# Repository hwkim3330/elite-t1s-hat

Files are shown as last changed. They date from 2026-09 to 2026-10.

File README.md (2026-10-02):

# Elite T1S HAT

A **10BASE-T1S** board for the **LilyGO T-ETH-Elite** (ESP32-S3), built around
the Microchip **LAN8651** MAC-PHY. It stacks on the Elite's 2×20 header and
gives it a single-pair automotive Ethernet port next to the Elite's own
100BASE-TX (W5500). This board is its own design, not a Raspberry Pi HAT on an
adapter.

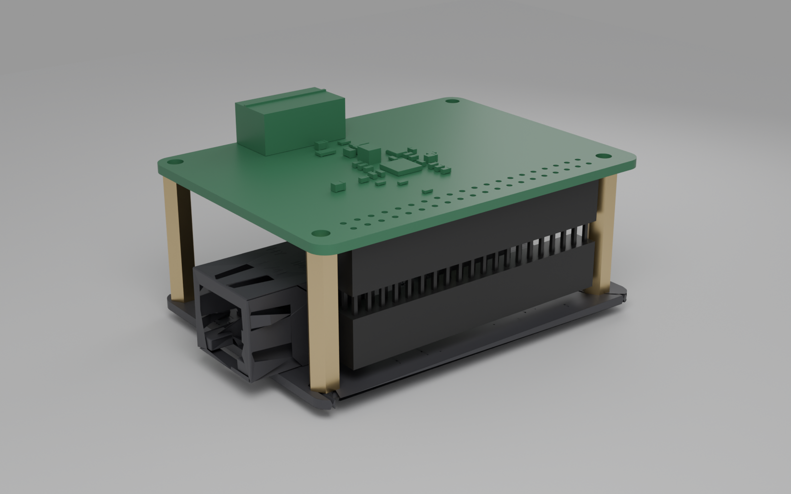
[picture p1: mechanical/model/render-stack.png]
The HAT on a T-ETH-Elite


**3D:** open [`mechanical/model/t1s_hat.stl`](mechanical/model/t1s_hat.stl) or
[`stack.stl`](mechanical/model/stack.stl) on GitHub to turn it in the browser.
There is also a STEP file for CAD work (`t1s_hat.step`).

| board, top | ground plane (In1) |
|---|---|
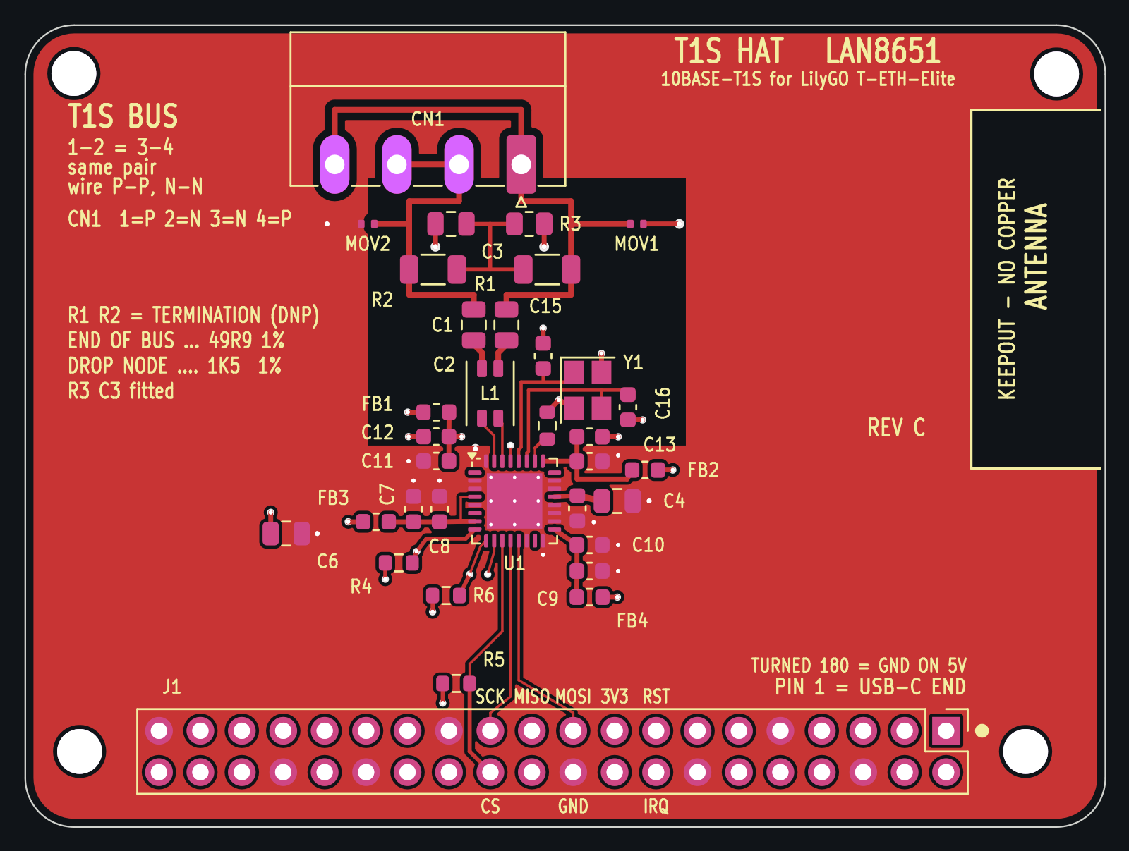
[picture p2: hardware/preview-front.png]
front
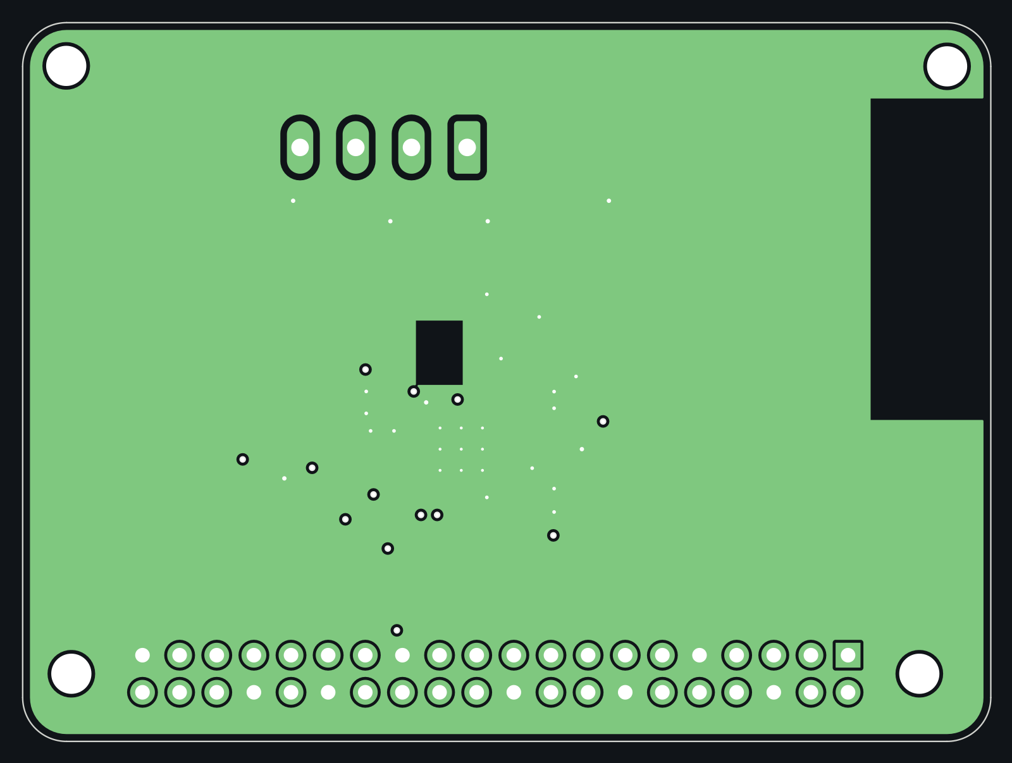
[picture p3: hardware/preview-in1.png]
In1.Cu
|  |  |

| folder | what |
|---|---|
| [`hardware/`](hardware/README.md) | KiCad schematic + **4-layer** PCB (Rev C; Rev B at tag `rev-b`), all generated by `make_t1s_hat.py`; gerbers; JLCPCB BOM/CPL. **[`ORDERING.md`](hardware/ORDERING.md) = how to order.** [`ELECTRICAL.md`](hardware/ELECTRICAL.md) = every value and why |
| [`firmware/`](firmware/README.md) | ESP32-S3 node firmware: LAN8651 over OPEN Alliance TC6 SPI, PLCA, ping/UDP, serial console |
| [`mechanical/`](mechanical/GEOMETRY.md) | outline, holes and header grid, measured from LilyGo's own DXF/3D (`reference/measure.py` re-derives them); `model/` has the 3D models (STL, STEP) and their build and render scripts |

## Status (2026-10-02)

| | |
|---|---|
| Design | **Rev C (4-layer) finished, ready to order**, with the pre-fabrication review fixes of 2026-10-02 (CCOMP, VDDAU, VDDA, RBIAS and crystal parts at their pins; exposed-pad paste clear of the thermal vias; see [`hardware/README.md`](hardware/README.md)). DRC 0 errors / 0 warnings, ERC 0 errors, mechanical error 0.00000 mm against `GEOMETRY.md`, 0 unrouted |
| Parts | every fitted part has an LCSC number, all in stock; **LAN8651 is the scarce one (199 at JLC, 2026-10-01)** |
| Firmware | compiles (Arduino esp32 3.3.0). It ran on a third-party LAN8651 HAT on the same pins (9.5 Mbit/s, PLCA, Zenoh); **not yet on this board, since none has been built** |
| Fabricated | **no.** Order 2–3 first, prove SPI + ping + PLCA between two nodes, then the rest |

What only a real board can settle is listed in
[`hardware/README.md`](hardware/README.md) under "What is NOT verified":
crystal oscillation margin, T1S signal quality and EMC, stack height.

## The short version of the design

- **LAN8651, single 3.3 V** from the Elite's header. The '51 regulates its own
  1.8 V core, so the board has no regulator.
- **Host SPI on the Elite's IO11/9/10, CS on IO0 (BOOT strap), IRQ IO39,
  RESET IO42.** These are the pins a Pi HAT would use, so the mainline
  `microchip,lan8651` driver also works on a Pi. Don't press BOOT on a
  running node.
- **Bus side per AN1718:** common-mode choke → 100 nF DC block → termination
  (fit per bus position: 49R9 end / 1K5 drop) → optional ESD → 4-pin 3.81 mm
  terminal block, wired P N N P so a node taps a daisy chain.
- **4 layers (since Rev B):** signals on top, In1 solid GND, In2 +3V3, bottom only three SPI escapes. The T1S pair is 50 Ω by construction (0.35 mm over 0.21 mm of prepreg). Rev A, the 2-layer version, is in git history.

## Where it is used

A networking test bench: ESP32-S3 nodes running Zenoh-pico behind two
TSN switches with FRER (IEEE 802.1CB). The nodes use the Elite's
own W5500 today; this HAT gives them a 10BASE-T1S edge link, and its firmware's
bridge mode joins a T1S segment to the switched 100BASE-TX backbone.

## History

Started as a sub-folder of an earlier adapter project (a Raspberry Pi HAT
carrier for the Elite) and split out on 2026-09-28 with its history, because the
board is its own product.

## License

MIT for everything written here; third-party parts keep their own licences
(listed in [`LICENSE`](LICENSE)).

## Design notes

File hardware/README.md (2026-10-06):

# T1S HAT — LAN8651 10BASE-T1S for the LilyGO T-ETH-Elite

Our own 10BASE-T1S board for the [LilyGO
T-ETH-Elite](https://github.com/Xinyuan-LilyGO/LilyGO-T-ETH-Series)
(ESP32-S3), built around a **Microchip LAN8651** MAC-PHY. It replaces buying
TSN Lab's ready-made HAT: same chip, same host header, our schematic.

Two source files govern this board and **nothing here re-derives a number in
either of them**:

| file | governs |
|---|---|
| [`ELECTRICAL.md`](ELECTRICAL.md) | every component, value and pin-handling rule, each quoted from Microchip DS60001734F or AN1718 (DS60001718D) |
| [`../mechanical/GEOMETRY.md`](../mechanical/GEOMETRY.md) | outline, mounting holes, 2×20 grid — measured from LilyGo's own DXF and 3D CAD |

Everything is generated by [`make_t1s_hat.py`](make_t1s_hat.py), which emits
the symbol library, the three project-local footprints, the schematic and the
PCB, then reads the board back and asserts every mechanical feature against
`GEOMETRY.md`.

**This is Rev C (2026-10-01, review fixes 2026-10-02), 4-layer: the design is
finished and ready to order.** Rev C is Rev B without the status LEDs and with
VDDA rerouted; an independent review before fabrication then moved the CCOMP,
VDDAU, VDDA and RBIAS parts and the crystal next to their pins and split U1's
exposed-pad paste (see "Rev C" below). It has not been ordered yet.
Rev B is at git tag `rev-b`. Rev A was 2-layer; its layout notes (the single-layer
crossings, JP1, the 3V3 rail) are in git history before commit "Rev B".

front

## What it is

- **LAN8651**, 32-VQFN 5×5, single 3.3 V rail (the '51 regulates its own 1.8 V
  core, so there is no second regulator and no sequencing diode).
- **OPEN Alliance TC6 SPI** to the host on the same header pins TSN Lab's
  device-tree overlay uses, so their SDK and the mainline `microchip,lan8651`
  driver both work unmodified if this board is ever put on a Pi.
- **Bus interface network** in AN1718's MINIMAL BIN order: common-mode choke →
  AC coupling caps → termination → ESD → 4-way 3.81 mm pluggable terminal
  block, wired so the node taps a daisy chain.
- **4 layers:** signals on top, In1.Cu solid GND, In2.Cu +3V3, bottom only the
  three SPI escapes. The T1S pair is 50 Ω by construction.
- 34 parts, 4 of them deliberately unstuffed (R1/R2 termination, MOV1/MOV2 ESD).

## The two parts that had to be chosen, not assumed

Both are drawn from their own data sheet into
[`fp/t1s_hat.pretty`](fp/t1s_hat.pretty), generated by `make_t1s_hat.py`
alongside the board, and the generator asserts the pad count and the overall
land size back out of the finished `.kicad_pcb`.

### L1 — TDK **ACT1210L-201-2P-TL00**, LCSC **C131444**

AN1718 names ACT1210D-131-2P-TL00, ACT1210E-241-2P-TL00 and Murata
DLW32MH241MX2, and says in the same breath that *"exact component part numbers
and parameters must be determined by the customer's unique application
requirements"* — they are examples. All three are **3.2 × 2.5 mm** (EIA 1210)
2-line chokes in the 130…240 µH @ 100 kHz band. The board previously sat on
KiCad's `Inductor_SMD:L_CommonMode_Wurth_WE-CNSW-1206`, a **3.2 × 1.6 mm**
land: same length, 0.9 mm too narrow, so the real part's terminals miss the
pads. KiCad ships no 4-terminal common-mode choke land in 3225.

The part fitted instead is the **ACT1210L-201-2P-TL00**: same ACT1210 package,
200 µH @ 100 kHz — inside the span AN1718's own examples cover — 70 mA,
5.5 Ω, AEC-Q200, and, unlike all three examples, **stocked at LCSC**
(C131444, ~$0.39/1k), which is where this board gets built.

Its land is `t1s_hat:L_CommonMode_TDK_ACT1210_3225`, drawn from TDK's ACT1210
data sheet "Layout recommendation" (drawing IND1512-9): **4.1 mm overall
across the pads with a 2.0 mm gap between the columns**, so each pad is
1.05 mm long on a 3.05 mm pitch, and **1.6 mm overall across the rows with a
0.4 mm gap**, so each pad is 0.60 mm wide on a 1.0 mm pitch. Body from the
same sheet: 3.2 ±0.2 long, 2.5 ±0.2 wide, 3.9 max over the terminals.

The symbol changed with it: the ACT1210's windings are **1-4 and 2-3**
(pin configuration and circuit diagram, same sheet), which is
`Device:L_Coupled_1423`, not the `…_1243` the 1206 Würth part needed.

### MOV1 / MOV2 — TDK **AVRH10C221KT1R5YA8**, LCSC **C2157827**

This is the part `ELECTRICAL.md` already names, and it is a **1005 [0402]**
chip varistor — 1.0 × 0.5 × 0.5 mm, 220 V V1mA, 70 V DC, **1.5 pF**, 25 kV per
IEC 61000-4-2. The board had it on `Resistor_SMD:R_1206_3216Metric`: three
size codes too big. It is now on `t1s_hat:Varistor_TDK_AVRH10_1005`, from the
recommended land pattern in TDK's automotive AVR chip-varistor catalogue
(pad 0.35…0.45 long, gap 0.3…0.5, pad 0.4…0.6 wide — the middle of each:
**0.40 long, 0.40 gap, 0.50 wide**). KiCad's `R_0402_1005Metric` is 0.54 ×
0.64 on a 1.02 mm pitch, outside all three ranges, which is why this one is
drawn here too. Both parts stay **DNP**; the land is now a real one.

## Rev B layout — what four layers bought

| | Rev A (2-layer) | Rev B (4-layer) |
|---|---|---|
| 3V3 | a rail round three sides of the board | **In2.Cu plane**, one via beside every 3V3 pad; no 3V3 trace exists |
| GND | B.Cu pour, one via per decoupling cap | **In1.Cu plane with no tracks at all**, plus F.Cu and B.Cu pours |
| VDDP pin 17 | 84 mm lap of the board through a 0 Ω jumper (JP1) | own ferrite-option island **FB4**, 0.01 + 0.1 µF at the pin |
| VDDP pin 7 | caps 7 mm away at the end of a column | C8 then C7 straight off the pin, FB3 behind them |
| SPI | MOSI looped out to the board edge and back; MISO ran between R5's pads | 2.5 mm fan-out: MISO/CS/SCLK drop through one via each to B.Cu, MOSI/IRQ/RESET stay on F.Cu, none crosses |
| T1S pair | 0.35 mm over 1.51 mm of FR4 — nowhere near 50 Ω | 0.35 mm over 0.21 mm of prepreg — **50.1 Ω** |

The rules the layout was held to, each checked by the generator or DRC:

- **In1.Cu and In2.Cu carry no tracks** (`plane tracks: 0`). Nothing slots the
  reference plane under the pair; the only cuts are the choke void AN1718
  asks for and the antenna window.
- **Every bus trace from the choke to CN1 is 0.35 mm** (`pair width` row).
- **Nothing passes between two vias.** The QFN's 0.5 mm pitch cannot fit a
  0.45 mm via plus 0.2 mm clearance each side with a track between, so the
  three B.Cu escapes are fanned out to a 1.1 mm pitch row first.
- **The B.Cu escapes turn right at staggered heights** (9 / 10 / 11 mm) and
  enter the header between pad columns, never across one of the Elite's
  pins that this board does not use.
- **The pull-ups cost no vias of their own:** R4 and R6 sit in-line on their
  F.Cu signal, and R5 lands on header pin 24's through-hole pad.

## Two decisions that are not in ELECTRICAL.md / GEOMETRY.md

### 1. No RJ45 notch — the outline is a plain rectangle

`GEOMETRY.md`'s notch exists because a board ~13 mm above the Elite would foul
the RJ45, which stands 15.97 mm. This board is lifted clear of the jack by a
taller riser instead, so nothing has to be cut away. Outline is the full
**66.22 × 49.19 mm rectangle, 3 mm corners**. Everything else mechanical in
`GEOMETRY.md` is unchanged and still authoritative: the four asymmetric
mounting holes and the 2×20 grid.

### 2. The connection is two-stage — read this before ordering parts

```
   T1S HAT  (this board)
        ↑ its 2x20 socket goes on the riser's long pins
   ── 2x20 stacking riser ──          ≈23 mm total (calculated), set by the riser
        ↑ riser socket swallows the Elite's own 9.30 mm pins
        ↑ RJ45 (15.97 mm) passes beside the stack, not through a notch
   LilyGO T-ETH-Elite (ESP32-S3)
```

**A single tall stacking header does not work here.** The Elite's pins are
only 9.30 mm long; they would reach barely halfway up a ~17 mm barrel whose
contacts sit near the top. You need a **riser** (a 2×20 stacking header that
plugs onto the Elite and presents longer pins) plus this board's **socket**.
That is a real failure mode someone will otherwise hit at the checkout page.

Board height above the Elite PCB is **≈23 mm, calculated** from the parts in
`ORDERING.md` (riser body 8.3 + ~6 mm of pin inside J1 + J1's 8.5 body), and set by the riser.
Nothing on this board depends on the exact number.

## Stack-up

JLCPCB **JLC04161H-7628**, 1.6 mm, written into the board file:

| layer | | thickness |
|---|---|---|
| F.Cu | signals, parts, GND flood | 0.035 mm (1 oz) |
| prepreg | 7628, εr 4.4 | 0.2104 mm |
| In1.Cu | **GND plane, no tracks** | 0.0152 mm (0.5 oz) |
| core | FR4 | 1.065 mm |
| In2.Cu | **+3V3 plane, no tracks** | 0.0152 mm (0.5 oz) |
| prepreg | 7628, εr 4.4 | 0.2104 mm |
| B.Cu | three SPI escapes + GND pour | 0.035 mm (1 oz) |

50 Ω single-ended on F.Cu over In1.Cu, IPC-2141:
Z0 = 87 / √(4.4 + 1.41) · ln(5.98 · 0.2104 / (0.8 · 0.35 + 0.035)) = **50.1 Ω**.
JLC's own calculator for this stack-up is the one to trust if it disagrees; ask
for impedance control when ordering and they will test it.

Design rules: 0.2 mm clearance (netclass), 0.15 mm minimum track, 0.45 mm vias
with 0.25 mm drill, 0.20 mm minimum drill (the QFN's thermal vias), and one
custom rule in `t1s_hat.kicad_dru`: **BUS_P/BUS_N keep 0.45 mm from every other
net** (pads, tracks, vias and the F.Cu flood). The one exception is inside each
MOV, whose own data-sheet land puts its BUS and GND pads 0.40 mm apart (the rule file relaxes clearance to 0.15 mm between pads inside each MOV courtyard, which covers that 0.40 mm gap).

## Termination stuffing — the one thing an assembler must decide

The board **ships with R1/R2 unstuffed**, per `ELECTRICAL.md` ("footprints
fitted, DNP by default — stuff per where this node sits on the bus"). The
silkscreen carries the table:

| where this node sits | R1, R2 |
|---|---|
| **end of the bus** | 49R9 1 % 1206 (AN1718: 1 W; the JLC variant fits 0.75 W — ORDERING.md) |
| **interior drop node** | 1K5 1 % 1206 |

`R3` (100 k) and `C3` (100 nF) — AN1718's common-mode termination — **are
fitted**. ESD elements MOV1/MOV2 have footprints and are DNP; `ELECTRICAL.md`
calls them optional.

`CN1` is wired **P N N P**, and the silkscreen carries that as a legend
(`CN1 1=P 2=N 3=N 4=P`) in the clear area to its left. Per-pad letters were
dropped: the four pads are 1.8 × 3.6 mm ovals with the connector's own body
outline 0.9 mm below them and R3/C3 0.6 mm below that, leaving a 0.6 mm slot —
nowhere to letter a pad without printing on copper. Pins 1–2 and 3–4 are the
same pair with opposite orientation, so wire P to P and N to N rather than
pin-for-pin. That order is what lets both on-board links be drawn without a
crossing.

## Verified

- **Mechanical: worst error 0.00000 mm** against `GEOMETRY.md`, tolerance
  0.01 mm, over the outline, all four mounting holes and all 40 header pads.
  `make_t1s_hat.py` prints the full table and exits non-zero on any failure.
- **Antenna keepout clean.** The generator walks every track, via, footprint
  and *filled zone polygon* on all four layers and counts anything inside
  x 58…66.22, y 22…44: **0 intruders.** The keepout is a rule area that forbids
  copper, tracks, vias, pads and footprints on all four layers, so both planes
  and both pours are cut out there. Silkscreen (ink, not copper) does mark the window.
- **In1.Cu and In2.Cu carry 0 tracks.** The T1S pair is 0.35 mm everywhere.
- **Unrouted connections: 0.**
- **L1 and MOV1/MOV2 lands read back as 4.10 × 1.60 mm on 4 pads and
  1.20 × 0.50 mm on 2 pads** — the data sheet numbers above, asserted out of
  the board file, not just written into it.
- **U1's exposed-pad paste covers no thermal via:** 12 windows, every one
  ≥ 0.15 mm off each of the nine 0.5 mm via lands, 51 % of the 3.4 mm land
  (`U1 EP paste` row).
- **ERC: 0 errors, 7 warnings** — see below.
- **DRC: 0 errors, 0 warnings, 0 unconnected** — see below.

### ERC — 0 errors

`kicad-cli` 7.0.11 has no `sch erc` subcommand, only `export`, so ERC is run
through the real eeschema on an Xvfb display by
[`run_erc.sh`](run_erc.sh), with **Show: All and Exclusions both ticked**
before the run. Report as produced: [`erc.rpt`](erc.rpt).

```
** ERC messages: 7  Errors 0  Warnings 7
```

All 7 warnings are the same thing: *"Pins of type Bidirectional and Power
output are connected"* on U1 pins 18, 19, 20, 22, 23 (DIOA0…4) and 16, 14
(DIOB0/DIOB1). Those are the unused configurable IO tied to ground, which is
exactly what the data sheet says to do — *"When not used, these pins may be
connected directly to ground."* Nothing is excluded or suppressed.

### DRC — 0 errors, 0 warnings

Run through `pcbnew.WriteDRCReport()` (same engine; `kicad-cli` has no
`pcb drc` either). Report as produced: [`drc.rpt`](drc.rpt).

```
** Found 0 DRC violations **
** Found 0 unconnected pads **
** Found 0 Footprint errors **
```

No clearance, hole, courtyard, keepout, solder-mask, silkscreen, unconnected-pad
or library-consistency finding. (The four mounting holes used to raise
`lib_footprint_issues`; their footprint is now written into the project library by
the generator itself, so the board copy and the library copy cannot differ.)
Nothing is excluded. Running it yourself reproduces exactly this.

## Inferences — things not taken from the spec files

Flagged because they are judgement, not quotation:

1. **U1 pin 1 (INH) is left unconnected.** `ELECTRICAL.md`'s pin-handling
   table does not cover INH. DS60001734F Table 3-5 says *"When not used, this
   pin should be left unconnected"*, so it is, with no copper stub.
2. **L1 is a 200 µH part where AN1718's examples are 130 and 240 µH.**
   AN1718 gives no minimum or maximum, only three example part numbers and an
   instruction to pick for the application; 200 µH is inside the span they
   cover and is the value TDK itself lists for one-pair automotive Ethernet.
   The land pattern is quoted, not inferred — but the *choice of value inside
   that span* is judgement.
3. **VDDP is split into two ferrite-option islands**, `VDDP` (pin 7, with
   TEST) on FB3 and `VDDP_17` (pin 17) on FB4. Both are fed from the same
   +3V3 plane, and with the default 0 Ω beads they are the same supply.
   `ELECTRICAL.md` asks for the bead option per supply; one per pin is the
   layout choice that keeps each pin's decoupling at the pin.
4. **The crystal is a 4-pad 3225, YXC X322525MOB4SI (C9006), CL 12 pF.**
   Until 2026-09-28 the board used a 2-pad 3.2 × 1.5 mm land. That was wrong:
   no 25 MHz crystal is made in that package, so the land matched no part.
   CL 12 pF rather than 18 pF is deliberate: 18 pF caps in series plus ~3 pF
   stray present 12 pF. Each lid pad (2, 4) has its own ground via; pad 2's is
   shared with R7's ground end beside it. Reasoning and margin numbers are in `ELECTRICAL.md`,
   "Clock".
5. **XTI is declared `passive` in the LAN8651 symbol**, not `input`. It is an
   oscillator pin driven by a passive crystal; declaring it an input makes
   KiCad's `pin_not_driven` test fire on a net that has no driver by design.
   Common practice, but it is a choice.
6. **The 40-pin header is a project-local symbol**, `t1s_hat:HAT_HEADER_2x20`,
   not `Connector_Generic:Conn_02x20_Odd_Even`. Its pins carry real electrical
   types (the six host signals are `output`/`input`, everything else
   `passive`), because the ESP32 side really is the driver and the generic
   connector's all-passive pins make ERC report every SPI input as undriven.
   The **footprint** is the stock `PinHeader_2x20_P2.54mm_Vertical`.
7. **Header pin 1 is at the USB-C (high-x) end, odd pins on the inner row
   (y = 5.900).** Rev A and early Rev B had this backwards (pin 1 at the low-x
   end on the edge row), inferred rather than measured. That was the exact
   180° opposite, and it would have put HAT GND on the Elite's 5 V. It is now
   taken from LilyGo's own pin-map image, cross-checked against the hole
   asymmetry and the antenna position (`../mechanical/GEOMETRY.md`), and
   asserted by the generator independently of `pin_xy()`: pin 1 must be the
   highest-x pad and on the inner row.
8. **`BIN_VOID` = x 21…40.5, y 23.4…39.8** and **`CMC_VOID` = x 26.90…30.10,
   y 24.40…28.80.** AN1718 asks for "a void in the ground flooding on the
   outside layer surrounding the BIN" and "an all-layer void underneath the
   CMC" **without giving dimensions**, so both sizes are judgement. The first
   follows the BIN components. The second is the only place other than the
   antenna window where the ground plane is cut, so it is sized to the
   part and no further: **the ACT1210's maximum body — 3.9 mm over the
   terminals × 2.7 mm wide (2.5 + tolerance) — plus 0.25 mm a side**, giving
   3.2 × 4.4 mm (L1 is rotated 90°, so the 3.9 runs along y). The margin
   covers placement tolerance and nothing else; the body is what couples to
   the plane, because the body is the core. That also covers the 4.1 × 1.6 mm
   land with room to spare. The void grew in x against the old number above,
   not because the margin grew but because the part did: the 1206 land it used
   to be sized around was the wrong part. Nothing but L1's own nets crosses it
   on any layer; VDDA passes on B.Cu 0.45 mm below it.
9. **The T1S pair necks to 0.15 mm at the QFN.** The package puts TRXP and
   TRXN 0.5 mm apart; AN1718's "3× trace width centre-to-centre to other
   signals" cannot be met between the pair's own two legs at a 0.5 mm-pitch
   QFN, and Microchip's own EVB does not either. It **is** met against every
   other net, by the F.Cu void around the BIN.
10. **Pair length match ≈0.2 mm.** TRXN opens out to the choke before TRXP
    does (so the gap only ever grows), which costs about 0.2 mm of mismatch —
    roughly 1.2 ps. Not measured on hardware.
11. **The stackup numbers** are JLCPCB's published JLC04161H-7628 build,
    taken as given, not measured. The 50 Ω figure follows from them.

## Files

| file | what |
|---|---|
| `ELECTRICAL.md` | **electrical source of truth** |
| [`ORDERING.md`](ORDERING.md) | **JLCPCB order: options, parts, what to hand-solder, what to check in the preview** |
| `jlcpcb/bom_jlc.csv` / `cpl_jlc.csv` | assembly files in JLC's column format, fitted SMT/THT parts only |
| [`../firmware/`](../firmware/README.md) | ESP32-S3 bring-up / node firmware (LAN8651 over TC6 SPI, PLCA, console) |
| `make_t1s_hat.py` | generator: symbol lib → schematic → PCB → verify → DRC → exports |
| `run_erc.sh` | runs eeschema's ERC headlessly (Xvfb + xdotool) and saves the report |
| `fill_zones.sh` | fills the zones through pcbnew's GUI — `ZONE_FILLER` segfaults in KiCad 7.0.11's Python bindings |
| `t1s_hat.kicad_sch` / `.kicad_pro` / `sym-lib-table` / `fp-lib-table` | schematic + project |
| `sym/t1s_hat.kicad_sym` | **LAN8651** (33 pins incl. the exposed pad) and the host header — neither exists in KiCad's libraries |
| `fp/t1s_hat.pretty/` | the TDK ACT1210 choke land and the TDK AVRH10 varistor land, each from that part's own data sheet — KiCad ships neither — and U1's QFN: KiCad's TQFN-32 5×5 with its exposed-pad paste split clear of the thermal vias |
| `t1s_hat.kicad_dru` | the custom DRC rule for the bus pair (written by the generator) |
| `t1s_hat.kicad_pcb` | the board |
| `gerbers/t1s_hat_gerbers.zip` | fab-ready: 10 gerber layers (4 copper), separate PTH/NPTH Excellon, drill maps, job file |
| `bom.csv` / `cpl.csv` | BOM (with a `Populate` column) and position file |
| `preview-front/back/in1/in2.png` (+ `.svg`) | all four copper layers |
| `erc.rpt` / `drc.rpt` | reports as produced, nothing excluded |

Regenerate with `python3 make_t1s_hat.py`. Geometry is reproducible to the
internal unit, but the output is not byte-reproducible — KiCad stamps fresh
UUIDs and timestamps on every run. Compare the printed coordinate table, not
the files.

Drill files and `cpl.csv` are plotted against the drill/place origin, which the
generator puts on `GEOMETRY.md`'s own origin, so `NPTH.drl` literally reads
`X3.33Y4.63` and `cpl.csv` reads `8.196, 3.360`.

## Bottom side

The board sits ~23 mm above the Elite. The J1 socket body occupies y 0…9 on
the bottom, and B.Cu carries only the three SPI escapes between the QFN and the
header. Everything else on the bottom is GND pour. Over the Elite's RJ45
(x −5.18…16.42, y 10.50…28.90) the clearance below is much less than
elsewhere, since the jack tops out at 15.17 mm above the Elite's PCB.

## Review notes (2026-09-29)

An external review of Rev B raised these; each was checked against the board
file and Microchip's documents before anything changed.

| point | finding | action |
|---|---|---|
| BUS_P 37.7 mm vs BUS_N 21.9 mm | True totals, but the **node's own stub is 15.92 mm on both**. The difference is the through-bus between CN1's two halves (18.1 vs 3.8 mm): ≈93 ps of skew against an 80 ns symbol, ≈ −43 dB mode conversion at 25 MHz. | Kept. The suggested "P N" in + "P N" out needs the pair to cross (vias in the bus network); the mirrored **P N N P** is what makes both links routable on one layer. |
| CCOMP "metal film" | Correct: the data sheet's body (DS60001734F) and the checklist both say "4.7 µF low ESR (metal film)"; only the pin table says "low ESR". *(An earlier version of this table said the data sheet does not — that was wrong.)* | C4 X5R → **X7R**, recorded in `ELECTRICAL.md` as a **non-compliant prototype choice** to verify on the first boards. |
| Ferrite islands need local 10 µF | Correct per the checklist, **only if a bead is fitted**. | FB1–4 documented as 0 Ω links; with 0 Ω the single C6 is compliant. |
| Test points for SPI/IRQ/RESET/3V3/GND | All eight are already adjacent J1 pads (pins 15–24), accessible from the top. | **Labelled** on the silkscreen instead of adding copper to the signal paths. |
| Series-R footprints on SCLK/MOSI | Series damping belongs at the **driver**. SCLK/MOSI are driven by the ESP32, on the Elite, not here. | Not added. The firmware lowers the ESP32's drive strength instead; MISO's driver (LAN8651) has its own pad-drive setting (PADCTRL). |
| 0.15 mm neck at the QFN | The pads are 0.25 mm wide on a 0.5 mm pitch, so the neck is the escape itself (TRXP 2.74 mm, TRXN 2.95 mm total). | Kept. |
| Stack height 18–20 vs 23 mm | Stale text in three files. | Fixed: ≈23 mm (calculated) throughout. |
| Antenna keepout | — | Unchanged. It is empty on purpose. |

## Rev C (current) — what changed from Rev B, and why

Rev B is kept, as designed (never ordered), at the git tag **`rev-b`**. Rev C changes only what the
bench and the data sheet showed was wrong, and it gets cheaper doing it.

| change | why |
|---|---|
| **Status LEDs D1/D2 and R8/R9 removed; DIOA0/1 to ground** | the LAN8651 has **no LED function**: PADCTRL A0SEL/A1SEL offer only event capture / event generator (DS60001734F §11.6.3), so Rev B's LEDs could never have shown PLCA state. Status is on the Elite's own LED (IO38), driven by firmware: solid = beacons seen, fast blink = no beacons, slow blink = no link. **Four parts fewer, two of them extended** (two JLC setup fees) |
| **VDDA leaves pin 29 through two vias** | Rev B ran it along the outermost top lane, 0.25 mm inside the choke's maximum outline. It now drops to B.Cu beside the pin, below the CMC void, and rises again at C12 (since the 2026-10-02 review fixes, at the top-left corner of U1; see below). The verifier's VDDA exception is gone: **nothing but L1's own nets crosses the void, on any layer** |
| silkscreen "REV C" | |

### Rev C review fixes (2026-10-02)

An independent review of the Rev C layout, before anything was ordered. Each
item was checked against the board file; distances are pad centre to pad
centre, lengths are routed copper.

| change | why |
|---|---|
| **C4 (CCOMP 4.7 µF) next to pin 21:** 6.1 → 2.9 mm, C5 2.3 → 1.4 mm; the trace is 0.30 / 0.40 mm (was 0.15) and 3.0 mm long (was 10.1); each cap has its own ground via | the core LDO's compensation was 10 mm of 0.15 mm trace away. DIOA0…4 now tie inward to the exposed pad, which freed the right edge of U1 |
| **U1 exposed-pad paste split into 12 windows clear of the 9 thermal vias** (51 % coverage, ≥ 0.15 mm off every via land); land, mask and vias unchanged | KiCad's stock paste squares covered the four corner vias, so solder would wick down them. The footprint is now a project-local copy (`…_SplitPaste`) |
| **C14/C13 (VDDAU) at pin 25:** 15.4 / 15.8 → 2.1 / 2.6 mm; FB2 behind them | pin 25's decoupling was 18 mm along a 0.15 mm trace |
| **C12/C11 (VDDA) moved to the top-left corner of U1:** pin to C12 7.1 → 5.0 mm of copper | still two vias and a B.Cu hop (pin 29 has the choke void above it and the crystal lanes to its right); the hop now passes under the TRXP/TRXN escapes, 0.45 mm below the void, with the In1 ground plane between |
| **R7 (RBIAS) on end beside pin 26:** 10.4 → 1.6 mm, trace 13.3 → 1.8 mm. RBIAS now runs within 0.6 mm of XTI for 1.4 mm (was ≈10 mm in parallel lanes 0.5 mm apart) | the bias resistor sat at the far end of a lane beside XTI. The crystal lanes now cross R7's grounded end and its via, never its RBIAS end |
| **Y1, C15, C16 closer:** XTI 15.7 → 10.0 mm, XTO 8.3 → 8.5 mm. Y1 is turned 270°; XTI runs between its pad rows to pad 3, each lid pad has its own via | XTI used to go out past the crystal and come back. XTO's length is unchanged because, as the outermost pin, it has to climb past R7; it keeps 0.2 mm from the choke void's edge |
| **Bus spacing enforced by DRC:** custom rule BUS_P/BUS_N ↔ any other net ≥ 0.45 mm. The two bus lanes moved 0.15 mm (to clear R1/R2's centre-tap pads) and the MOV stubs end on the near half of their pads | the generator's comment claimed this rule (and a 2-layer board); neither was true, and its net-class table never reached the board. The classes now carry the board's real 0.2 mm and survive the save |
| **Silkscreen at J1: "PIN 1 = USB-C END" and "TURNED 180 = GND ON 5V"** | the socket goes on either way round, and turned 180° it puts this board's GND (pin 39) on the Elite's 5 V (pin 2) |
| `erc.rpt` regenerated (it was from Rev B); oscillator gm corrected in `ELECTRICAL.md` | DS60001734F §8.6 does give the gm: 18.2 mS nominal, ≈16× the crystal's 1.1 mA/V |

Three designators (C5, C14, R7) are left off the silkscreen: there is no free
spot beside them that would not read as a neighbour's. They are in `bom.csv`,
`cpl.csv` and the assembly files as usual.

Considered and **not** done, on purpose:

- **A node-ID DIP / a termination switch.** Physical switches cost money and space,
  and a bench or harness node is configured once. ID and count stay in firmware
  (console + NVS, settable over Zenoh); termination stays a choice at order time
  (`jlcpcb/end/` vs `drop/`), and the 1206 parts are easy to hand-fit later.
- **A metal-film CCOMP.** No 4.7 µF film capacitor exists in SMD at JLC (only
  ≥ 22.5 mm-pitch through-hole). C4 stays X7R; the LAN8651 HAT that ran at line
  rate on the bench (9.5 Mbit/s, 0 loss) is the evidence it works.
- **Separate 1 mm test pads.** J1's pads are labelled probe points with GND beside
  them; adding stubs to the SPI lines buys little.

Measured with a LAN8651 HAT on this firmware (2026-10-01): SPI 25 MHz asked (26.67 MHz actual) → 9.0 Mbit/s
PC → node without loss, 9.5 node → PC, ping 0.85 ms; with PLCA no node-side loss in
any contention test, where CSMA/CD lost up to 27 %. Full report and the design
lessons behind Rev C: <https://github.com/hwkim3330/t1s-eval>.

### Bring-up order for the first boards

1. Power: 3.3 V rail, then **CCOMP ≈1.8 V** (level and ripple — the X7R check)
2. SPI: DEVID read (MMS10 0x94)
3. RESET and IRQ lines
4. T1S link up — the Elite's LED goes solid once PLCA beacons are seen
5. PLCA, node 0 and node 1
6. Ping
7. UDP throughput — 9 Mbit/s each way at SPI 25 MHz asked (26.67 actual) is what the reference reached
8. Zenoh (build with `-DT1S_WITH_ZENOH`)
9. Scope TRXP/TRXN at the connector

**Still a prototype build:** C4 is X7R where Microchip asks for metal film, R1/R2
are 0.75 W where AN1718 lists 1 W, and L1 is a 200 µH choke outside AN1718's named
examples. Each is documented in `ELECTRICAL.md`.

Next step after this HAT: a standalone T1S node board (ESP32-S3 + LAN8651 + USB-C
on one PCB, no stacking), running Zenoh on the node itself.

## What is NOT verified — read before ordering

- **This PCB has not been built.** The firmware and the measurements ran on T-ETH-Elite boards with a third-party LAN8651 HAT on a 2×20 riser (see `firmware/README.md`), not on this board.
- **The two project-local lands come from data sheets, and have now been
  cross-checked against a second, independent source.** L1 was drawn from TDK's
  ACT1210 layout recommendation, MOV from TDK's AVR catalogue. On 2026-10-01 both
  were compared with the EasyEDA footprints JLC places for those LCSC numbers. **L1:**
  same pitch (1.0 × 3.05 vs 3.15 mm), same width (0.60 mm) and the same 2.0 mm inner
  gap; JLC's pads are 0.10 mm longer at the outer toe (1.15 vs 1.05 mm). That is
  solder-fillet margin, not a placement error, and `check_jlc_cpl.py` puts every pad
  within 0.15 mm. **MOV:** JLC only has a generic R0402 land (0.57 × 0.54 mm,
  0.87 mm pitch); ours is TDK's own (0.40 × 0.50 mm, 0.80 mm pitch). The MOVs are
  hand-fitted, so ours is the one that counts.
- **Stock was read on 2026-10-01 from JLC's own assembly warehouse, not ordered
  against.** All 15 lines of the `end/` BOM are in stock. The scarce one is **U1, LAN8651B1-E/LMX
  (C22386973): 199 at JLC.** Check it first. LCSC retail shows R4–R6 (10k 0603,
  C25804) at 0, but that is LCSC's shop. JLC assembles from its own stock, which
  has 23 million.
- **The pair's 50 Ω is calculated, not measured.** Order JLC impedance
  control if you want it tested. T1S signal quality and EMC need a built board.
- **Oscillator margin is computed from a nominal figure.** The crystal needs
  gm_crit ≈ 1.1 mA/V; DS60001734F §8.6 gives the LAN8651's oscillator
  transconductance as 18.2 mS nominal, a margin of ≈16. Nominal is not a
  guaranteed minimum, so check it on the first board (`ELECTRICAL.md`, "Clock").
- **The riser stack height (≈23 mm) is calculated, not measured.** Nothing on the
  board depends on the exact value, but the standoffs do: measure one stack first.
- **No order was placed.** The deliverable is fab-ready files to upload.

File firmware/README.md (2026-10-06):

# T1S HAT firmware

`t1s_node/` brings the HAT's LAN8651 up on a LilyGO T-ETH-Elite as a normal
`esp_netif` Ethernet interface, so lwIP (ping, UDP, sockets) runs over
10BASE-T1S unchanged. It is the bring-up tool for the first board and the
base that a larger node firmware can fold in beside the W5500.

**Status: runs on hardware** (three T-ETH-Elite boards, with a third-party LAN8651 HAT on
the same header pins; see "Not done / not verified" for exactly what ran). This HAT's own
board has not been built yet. Every stage a first power-up can fail at prints what it saw;
see "First power-up" below.

## Build and flash

Run from this `firmware/` folder. Arduino core `esp32:esp32` 3.3.0 (ESP-IDF 5.5), the same toolchain as
the W5500 bench firmware this was developed next to:

```bash
FQBN="esp32:esp32:esp32s3:PSRAM=opi,USBMode=hwcdc,CDCOnBoot=cdc,FlashSize=16M,PartitionScheme=app3M_fat9M_16MB"
arduino-cli compile --fqbn "$FQBN" t1s_node
arduino-cli upload  --fqbn "$FQBN" -p /dev/ttyACM0 t1s_node
arduino-cli monitor -p /dev/ttyACM0 -c baudrate=115200
```

**Partition scheme:** `app3M_fat9M_16MB` gives two 3 MB app slots, so OTA has room. The
build with zenoh is 1.16 MB, which would be 88 % of the default 1.25 MB slot. The first flash
with this scheme has to go over USB, because it rewrites the partition table. After that,
every update can go over WiFi.

### Over WiFi: console and OTA

Every board brings up WiFi last in `setup()` and offers two services:

| | |
|---|---|
| console | TCP port 23 (`nc <ip> 23`). It is the same console as USB serial, and everything printed goes to both |
| OTA | ArduinoOTA, hostname `t1s-<last 4 hex of MAC>`, announced over mDNS. The password defaults to `t1s-ota`; change it with `ota <pass>` + reboot |

```
wifi <ssid> <pass>    join that network as a station (saved; on reboot)
wifi ap               no network: open its own AP "t1s-<id>" (pass t1s-bench), 192.168.4.1
wifi                  show WiFi / OTA / console state
```

Update over WiFi:

```bash
arduino-cli upload --fqbn "$FQBN" --protocol network --port <board-ip> \
  --upload-field password=t1s-ota t1s_node
# or: python3 ~/.arduino15/packages/esp32/hardware/esp32/*/tools/espota.py \
#       -i <board-ip> -a t1s-ota -f <build>/t1s_node.ino.bin
```

The WiFi console uses a different subnet from the T1S / W5500 side, so test traffic never
goes over WiFi by accident. A bench console can find the boards by mDNS (`_telnet._tcp`,
`t1s-*`), or take them by IP.

Built here (2026-10-02): 1.07 MB without zenoh, 1.17 MB with it (34 % / 37 % of a 3 MB slot). No warnings from the sketch, the bridge or
the LAN865x driver. The copied `w5500_spi.h` shows its original volatile-`++`
warnings.

Check which board `/dev/ttyACM0` actually is before uploading: on this
machine it is also the LAN9662, and `arduino-cli board list` has been wrong
about it before.

## What is in it

| | |
|---|---|
| `t1s_node.ino` | bring-up, PLCA, UDP echo on port 7, serial console |
| `pins.h` | HAT signal → Elite GPIO, read off LilyGo's schematic (and why CS_N on IO0 is fine) |
| `bridge.h` | bridge mode: W5500 bring-up (no IP, promiscuous) + the two-port learning forwarder |
| `w5500_spi.h` | from the W5500 bench firmware: the W5500 SPI layer that splits reads at the RX buffer wrap (a real IDF driver bug found there) |
| `src/lan865x/` | Espressif's `lan865x` 0.2.0 + `lan86xx_common` MAC-PHY driver, Apache-2.0, vendored with one marked patch (raw register access). See `VENDORED.md` |

The driver talks OPEN Alliance TC6 over **SPI3** (MOSI IO11, MISO IO9,
SCLK IO10, CS IO0) with IRQ_N on IO39. It uses SPI3 because the W5500
firmware already uses SPI2, so the two can later share one image as a
T1S ↔ 100BASE-TX bridge.

## Modes

`mode node|bridge|sniff|tx`, then `save` and `reboot`. The mode lives in NVS.

| mode | what the board is | IP | status |
|---|---|---|---|
| **node** (default) | a 10BASE-T1S endpoint: lwIP on the LAN8651, ping / UDP echo / `blast`; the Elite's own RJ45 (W5500) comes up next to it as a second interface, see below | yes, 192.168.50.x (+ LAN: DHCP) | **run** (LAN: driver and PHY up, no cable yet) |
| **bridge** | a **learning Ethernet bridge** between the Elite's W5500 (100BASE-TX) and the LAN8651 (10BASE-T1S), `bridge.h` | none, managed over USB serial | compiles |
| **tx** | **no LAN8651:** the Elite's W5500 as an ordinary IP endpoint (echo, sink, `blast`, `ping`), default 192.168.100.66. This is the second board of a two-ESP bench, in the PC's place on the converter's 100BASE-TX port | yes, W5500 | **run** |
| **sniff** | a **receive-only bus analyser**: every T1S frame is copied out of the W5500 to a capture PC (Wireshark). PLCA is held off, there is no IP, and nothing is sent on T1S, so the bus under test is not disturbed | none | compiles, not run |

**The RJ45 in node mode.** Until 2026-10-06 node mode never started the W5500, so the board's
own LAN port was dead while the HAT ran -- not an SPI conflict (W5500 on SPI2, LAN8651 on SPI3;
bridge mode runs both). Now `lan dhcp` (default), `lan <ip> [mask]` or `lan off`, then `save` +
`reboot`. It is a separate interface on its own subnet, nothing is forwarded to T1S (that is
bridge mode), and its route priority is below T1S's, so the default route and Zenoh's multicast
stay on the bus. Echo (7), sink (9), the TCP console (23) and OTA answer on it too. `status`
prints `lan: up|down ip ...` and the W5500's PHYCFGR. Keep its subnet off T1S's (192.168.100.x on
the bench). The W5500 has no auto-MDIX: to another W5500 board use a crossover cable.

Sniff is the converter's "ID ≥ 1, count 0" mode on this board. Wire the W5500 port
straight to the capture PC, not through a switch (the switch would learn the T1S
stations on that port). `status` shows frames seen / copied / dropped. The saved PLCA
settings are kept and come back when the mode is switched back to node.

Bridge mode is what turns the board into a D10-backbone ↔ T1S-edge gateway.
T1S nodes behind it reach `zenohd` on the PC as if they were on the switch.
Zenoh itself doesn't need to know a bridge exists, which is why this is L2 and
not a Zenoh-level gateway: zenoh-pico is a client/peer and cannot route, so a
Zenoh "gateway" would mean re-publishing named keys by hand.

How it works, and its limits:

- **Both drivers already deliver raw frames.** The IDF W5500 driver runs the
  chip in MACRAW, and the LAN865x is a MAC-PHY. Bridging means taking each
  driver's input path away from lwIP and transmitting on the other port. Both
  ports run in promiscuous mode.
- **It learns MAC addresses** (64 stations, 300 s ageing). Unicast between two
  hosts on the 100 Mbit side is never copied onto the 10 Mbit bus.
  Broadcast/multicast is forwarded both ways, because ARP needs it. So connect
  the bridge to an edge port, not a trunk.
- **Throughput is bounded by the slow side and the SPI hops.** The T1S bus is
  10 Mbit/s shared and half duplex. The W5500 path measured ~8 Mbit/s in
  the W5500 bench. When the LAN8651 has no TX credits the frame is dropped
  and counted (`status` → "dropped (no TX room)"). TCP backs off; UDP floods
  lose frames.
- **One bridge per T1S segment.** There is no spanning tree. Two bridges from
  the same bus into the same switch fabric make a loop.
- The ESP32 in the middle is also a place to add filtering, VLAN handling,
  delay/loss injection or timestamps later. None of that is written yet.

IP routing is also possible (`CONFIG_LWIP_IP_FORWARD` is on in this core, with
two subnets and a static route on the PC). It isn't implemented, because the
bridge already covers the test-bench use.

## Console

```
status                     link, ip, PLCA as read back, chip id, PADCTRL
plca <id> [count]          PLCA node id (0 = coordinator) and node count
csma                       PLCA off, plain CSMA/CD
ip <a.b.c.d> [mask]        static address (default 192.168.50.10+id)
spi <mhz>                  starting SPI clock 1..25, on reboot (default 25, steps down by itself)
ping <ip> [n]              ICMP over the bus
blast <ip> [sec] [bytes] [port] [mbit]  UDP (port 9), seq-numbered; mbit paces it
sink [reset]               what arrived on port 9: rate, then `sinkx:` seq loss / reorder / dup, arrival-gap p50/p90/p99/max
rtt <ip> [n] [bytes] [ms]  UDP echo round trip timed in us (one in flight), summary + every sample (`rtts:`)
counters                   TC6 status/errors, TX credits, RX chunks, PLCA beacons
identify [sec]             strobe the board LED to find the board
promisc on|off             accept every frame (tells "nothing arrives" from "filtered")
phyreset                   (mode tx) W5500 PHY reset with autonegotiation
phy auto|10h|10f|100h|100f (mode tx) W5500 link mode, written to PHYCFGR
rxlog                      last received frames: source, destination, type
reg r|w <mms> <addr> [val] raw LAN8651 register (hex)
mode node|bridge|sniff|tx  what the board is (save + reboot)
wifi [<ssid> <pass>|ap|off] WiFi station / own AP / no radio (on reboot)
ota <pass>                 OTA password (on reboot)
zenoh [status|pause|resume|ping <hz>|rtts|blast <s> <B>|sink]
save / reboot
```

Settings live in NVS (`t1s` namespace). A fresh board comes up with **PLCA off
(CSMA/CD), 192.168.50.9, SPI at 25 MHz**.

**Asked vs actual SPI clock.** The ESP32-S3's SPI peripheral divides 80 MHz by an integer and rounds to the
nearest divider, so `spi 25` used to run at **26.67 MHz** -- above the LAN8651's 25 MHz maximum (DS60001734F,
Table 9-9, f<sub>SCK</sub>). Since 2026-10-06 bring-up lowers the request until the clock that runs is
<= 25 MHz: `spi 25` and `spi 22` run at **20 MHz** (80/4, the fastest in-spec clock on this chip), `spi 18`
and `spi 15` at 16, `spi 12` at 11.43. Bring-up prints both (`t1s: SPI 25 MHz asked, 20.00 MHz actual`) and
`status` shows the actual one. Every "25 MHz" result in these docs and the reports before 2026-10-06 was
measured at 26.67 MHz, out of spec.

**SPI clock fallback.** Bring-up tries the saved clock, then 20, 12 and 4 MHz, and keeps the
first one the driver installs at (the driver checks parity on every control reply, so a clock
the wiring can't carry fails install instead of corrupting data). The boot log prints each
attempt, and `status` shows the clock it ended up on. A board that only came up at 12 MHz
says so without anyone setting `spi 12`.

**Counters.** `counters` prints only registers the driver itself uses: TC6 STATUS0/1, the
current TX credits / RX chunks, and PLCA_STS. A first version also read a guessed MAC
statistics block (Cadence-GEM layout, MMS 1 words 0x42…0x69). On a real LAN8651 every
value read 0, and **reading it every 5 s stopped the chip from transmitting**, so it is gone.
Frame counts come from `rx t1s` / `rx w5500` in `status`, which count what the driver hands
up and need no register map.

## First power-up: what each line means

| log line | meaning |
|---|---|
| `t1s: spi bus: ESP_OK` | bus pins claimed. Anything else is a firmware conflict, not the HAT |
| `t1s: driver install: ESP_OK` + `t1s: chip LAN8651 rev N` | **SPI reaches the chip.** This is the main hardware test |
| `driver install: ESP_ERR_TIMEOUT` / `ESP_ERR_INVALID_CRC` | SPI is not getting through: riser seated? 3V3 on header pins 1/17? try `spi 4`, `save`, `reboot` |
| `driver install: ESP_ERR_INVALID_VERSION` | a chip answered with the wrong ID: bit errors, lower the clock |
| `plca: on, id …` | read back from the PHY, not echoed from config |
| `t1s: link up` | the PHY reports link. On T1S that needs a correctly terminated bus (see below) |

## Two-node bench test

T1S is a bus, and a two-node bus is **two end nodes**: both HATs get
R1/R2 = 49R9 (the README's termination table). Then:

```
node A:  plca 0 2      save  reboot     # coordinator, 2 nodes -> 192.168.50.10
node B:  plca 1 2      save  reboot     # -> 192.168.50.11
node A:  ping 192.168.50.11
node A:  sink reset
node B:  blast 192.168.50.10 10
node A:  sink                            # what actually arrived
```

Wire CN1 P to P and N to N (pins 1/4 are P, 2/3 are N). With PLCA on both,
`blast` reports what left node B, `sink` on node A what arrived; the gap
between them is loss on the bus. Targets: **3–5 Mbit/s** delivered at first,
**7–9 Mbit/s** once tuned (SPI clock, frame size). `blast` should approach the bus rate; with `csma` on both it will still work,
with random backoff instead of fixed slots.

A PC can only join with its own T1S interface (e.g. a USB 10BASE-T1S
adapter). With the Linux `lan865x` / `onsemi` T1S drivers the PC side is
set with `ethtool --set-plca-cfg <if> enable on node-id <n> node-cnt <m>`.

## Not done / not verified

- **Run on hardware with a third-party LAN8651 HAT, not yet with this board.**
  TSN Lab's 10BASE-T1S HAT uses the same header pins (SPI0 CE0, IRQ on pin 16), and
  this firmware drove it unmodified on a T-ETH-Elite: DEVID, PLCA, ping, 9.5 Mbit/s,
  Zenoh. This HAT's own boards are not built yet.
- **Status LED:** the LAN8651 has no LED function (its DIOA pins are event
  capture/generator only), so the firmware drives the Elite's own LED (IO38)
  from PLCA_STS: solid = beacons seen, fast blink = no beacons, slow blink = no
  link. Rev C boards have no LEDs of their own.
- **SPI clock:** 25 MHz is the default request (20 MHz actual, see above), with the automatic step-down. A LAN8651
  HAT ran clean at 25 MHz asked (26.67 actual, out of spec, before the clamp): 9.0 Mbit/s to the node and
  9.5 from it, against 6.0 / 6.3 at 12 MHz asked (11.43 actual). The to-node rates were read
  by the board's sink, which then ran ≈0.5 % high (fixed in cf0ba44); see the
  [errata](https://github.com/hwkim3330/t1s-eval/blob/main/ERRATA.md). The step-down itself has not run on hardware.
- **Run on hardware (2026-10-02, three Elite boards):** `mode tx`, the SPI step-down (no HAT:
  25 → 20 → 12 → 4, fails cleanly, console stays up), the WiFi AP + TCP console (a PC joined
  `t1s-9c3c` and ran `status` over `nc`), **OTA** (espota over the AP, 1.17 MB in 14.7 s,
  `ota: done` → reboot → LAN8651 up → Zenoh session up), Zenoh peer-to-peer, `rtt`, sink
  statistics. **Not run:** sniff mode, bridge mode with this firmware, Zenoh remote config.

## Zenoh-pico over T1S (optional)

Build with zenoh-pico on the library path and two flags. The node then joins Zenoh over its wired
interface (T1S on a HAT node, the W5500 in `mode tx`):

```bash
F="-DZENOH_ARDUINO_ESP32 -DT1S_WITH_ZENOH"     # add -DZENOH_ROUTER='"udp/<ip>:7447"' to use a zenohd
arduino-cli compile --fqbn "$FQBN" --library <path>/zenoh-pico \
  --build-property "compiler.c.extra_flags=$F" --build-property "compiler.cpp.extra_flags=$F" t1s_node
```

**Default: peer to peer over UDP multicast (`udp/224.0.0.224:7447#iface=eth`), no router.** Two
boards form a Zenoh network on their own. (`#iface=` is required by zenoh-pico's multicast locator
check; the ESP32 port ignores its value and lwIP sends from the default netif, the wired one.)

**Wireshark.** [`tools/zenoh.lua`](../tools/zenoh.lua) decodes it: copy it to `~/.local/lib/wireshark/plugins/`
(or `tshark -X lua_script:tools/zenoh.lua`). UDP 7447 then shows `JOIN peer <zid>`, `PUT t1s/t1s-hat-0/signal '23.69'`,
DECLAREs, and a tree down to the key expression and payload; written against zenoh-pico 1.10.1's codec.

**TTL 1.** 224.0.0.0/24 is link-local (RFC 3171/5771) and must be sent with TTL 1; lwIP's default is 64,
which Wireshark colours red on every Zenoh datagram ("TTL low or unexpected"). zenoh-pico sets no
multicast TTL, so the vendored copy is patched: [`zenoh-pico-multicast-ttl1.patch`](zenoh-pico-multicast-ttl1.patch)
(`patch -p1` inside the zenoh-pico folder). Checked on a capture: all 551 datagrams TTL 1, no expert notes.

| key | |
|---|---|
| `t1s/<node>/hello`, `/signal`, `test/stats/<node>` | 2 Hz, 20 Hz, 1 Hz |
| `test/ping/<node>` → `test/pong/<node>` | every board echoes every other board's ping; each measures its own RTT |
| `t1s/<node>/bulk` | `zenoh blast`, counted by `zenoh sink` on the other board |
| `t1s/<node>/cmd`, `/config` → `/config/ack` | console text, remote config |

`<node>` is `t1s-hat-<PLCA id>` on a HAT node and `t1s-eth-<mac>` on a W5500-only board.

```
zenoh [status] | pause | resume | ping <hz> | rtts [reset] | blast <sec> <bytes> [batch] | sink [reset]
```

Measured on the two-ESP bench (2026-10-02, report in `t1s-eval/two-esp/`): pub/sub RTT 5.6–6.0 ms
median; up to 5.5 Mbit/s of payload. Small messages stop near 1000/s — on the **publisher**: unbatched,
every put is its own UDP datagram and the put call takes ~1 ms; the subscriber received every one it was
sent. `zenoh blast <s> <B> batch` wraps the run in `zp_batch_start/stop`: 64 B puts then take ~130–150 µs
and reach ~5500–6000 msg/s (2026-10-06, SPI 20 MHz); 1024 B gains nothing (one message fills a datagram).
Batching delays each put until its batch is flushed, so it is for bulk, not control traffic.

Where the Zenoh round trip goes: raw UDP between the same two boards is 2.97 ms (most of it the
W5500's 1 ms receive poll on the ESP-B side; PC ↔ HAT measured 0.85 ms). Echoing a ping the moment
its callback fires (task notification instead of the 2 ms loop) and publishing ping/pong as
`is_express` brought the Zenoh median from 6.14 to **5.20 ms** pinged from ESP-B and from 5.58 to
**5.26 ms** pinged from the HAT (2026-10-02, 480/449 samples at 50 Hz). The remaining ~2.3 ms over
raw UDP is inside zenoh-pico. (A first measurement showed no change; the HAT was still running an
image an earlier OTA had put in the other app slot -- see "Flashing after an OTA".)

### Time sync (`sync`, `ptp`)

`sync <ip> [n] [ms]` runs the two-way time-transfer exchange PTP and NTP use (t1..t4) against
`<ip>`'s UDP 5007 and prints clock offset and one-way delay per exchange; the console's *Time sync*
panel runs it and plots the result. With software timestamps on both boards (ESP-B's W5500 adds
its 1 ms receive poll on one direction) the offset scatters by **σ ≈ 150–220 µs**, **≈ 50 µs**
using the lowest-delay 10 %, **≈ 40–50 µs** taking one min-delay exchange per 2 s; the two crystals
differ by ~1–3 ppm (2026-10-06). Precision only: there is no reference clock on the bench.

**Hardware timestamps (`ptp on`, build with `-DLAN865X_FRAME_TIMESTAMPS`).** The LAN8651 has a 1588 wall
clock (TSU, 40 ns ticks), prepends an ingress stamp to received frames and captures a frame's egress
time (OA_CONFIG0 FTSE/FTSS, TC6 header TSC, TTSCA). The driver carries hooks for both
(`esp_eth_mac_lan865x_set_ts_hooks`); `ptp on` connects them and `sync` then also reports offsets
from the node's hardware stamps, sent in a follow-up as PTP does. Two things had to be found:

- FTSE/FTSS take effect only when written **with SYNC at init** (later writes read back set but do
  nothing, and SYNC cannot be cleared) -- hence the build flag, which costs 8 bytes of SPI per
  received frame.
- The stamp is triggered by the **PHY's packet matcher** at the SFD on the wire (DS60001734F 4.5.2.2),
  which out of reset is **off** and set to gPTP Sync only. Symptom: STATUS1.TTSCMA ("capture requested,
  not triggered"), no RTSA. `ptp on` sets it to match every frame (mask 0xFFFFFF, location 0,
  TXMCTL/RXMCTL enable) as Microchip's drivers do; the vendored driver has those writes on a path
  this chip revision does not take.

Measured 2026-10-06, node hardware vs ESP-B software (W5500): offset σ per 2 s **16.7 µs** (software on
both sides 43 µs), lowest-delay 10 % 31 µs; the TSU runs off the HAT's 25 MHz crystal, ~20 ppm from
the ESP32's. The far side is the limit here (W5500 poll, converter, PLCA wait): hardware-to-hardware
needs a second LAN8651 node.

**Clock servo (`ptp lock <ip> [sec] [kp] [ki]`).** The node disciplines its LAN8651 clock to a
master's, as ptp4l steers a PHC: 16 exchanges a second with its own request and the reply stamped
in hardware, the min-delay one per second, one step (TA register below 1 s, else TSL/TN), then a PI
loop on the TSU frequency -- TI (ns) plus TISUBN (2^-24 ns; its 24 bits are split: low byte in
31:24, high 16 bits in 15:0; write TISUBN before TI). The request spacing is jittered by 0–1 ms:
at a whole-ms spacing every request meets the master's 1 ms W5500 poll at the same phase and the
min-delay pick has nothing to choose from. Against ESP-B (software stamps, W5500) on 2026-10-06:
offset after 20 s **mean −3.4 µs, σ 32 µs** (max 130), frequency held at **−22.3 ppm** (the HAT's
25 MHz crystal against the ESP32's); ptp4l's gains (0.7 / 0.3) amplify this bench's ~50 µs
measurement noise into ±40 ppm swings, 0.2 / 0.02 is the default.

Then, on the master's side (ESP-B), step by step, 120 s runs, offset after 20 s:

| change | σ | max | one-way delay p50 |
|---|---|---|---|
| W5500 polled every 1 ms (above) | 32 µs | 130 µs | 750 µs |
| **W5500 interrupt on IO14** (the Elite wires INTn there) | 18.5 µs | 52 µs | 736 µs |
| **+ t2 stamped at the driver** (RX tap, before lwIP and the socket task) | 11.6–14.9 µs | 28–48 µs | 520 µs |
| t3 taken after the send returned (two-step) -- reverted | 23 µs | 78 µs | 193 µs |

Mean offset −0.3 … −1 µs, frequency −20.8 … −21.0 ppm ± 2.5–3 ppm. The rest is the master's
software stamps and the converter; two LAN8651 nodes (hardware on both ends) are the next step,
and the servo already uses a master's hardware follow-up when it gets one.

**PPS (`ptp pps on force` / `off`, not yet run on hardware).** Event generator 0 drives DIOA0 high for
100 ms at every whole second of the LAN8651 clock, so two locked nodes' pulses on a scope show the
sync error directly. DIOA0 becomes an output: **never on a board that ties DIOA0 to ground** -- Rev C
of this HAT does (they were unused when it was drawn), hence the `force`.

**Throughput cost.** `-DLAN865X_FRAME_TIMESTAMPS` adds an 8-byte stamp to every received frame on
SPI: onto T1S (1472 B, 9.5 offered) 8.75 → 8.20 Mbit/s (−6 %); transmit unchanged. Hence a build
option, not the default. The W5500 interrupt costs nothing (8.76 polled, 8.75 interrupt) and lifts
64 B frames from 1.97 to 2.26 Mbit/s; `-DW5500_POLL` keeps the old 1 ms poll for comparisons with
runs taken before 2026-10-06 evening.

### Flashing after an OTA

An OTA writes the *other* app slot and points `otadata` at it. A later USB flash of the app at
0x10000 alone then does nothing visible: the board keeps booting the OTA'd image. Erase
`otadata` with it (`esptool erase-region 0xe000 0x2000`), or flash the merged image from 0x0.

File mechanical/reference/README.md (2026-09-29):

# LilyGo mechanical files, fetched on demand, and the script that reads them

Everything dimensional in `../GEOMETRY.md` traces back to three files LilyGo
publish for the T-ETH-Elite. **They are not stored in this repository:** LilyGo's
repository states no licence, so they are downloaded from upstream when needed
and ignored by git.

```bash
pip install --user ezdxf trimesh manifold3d py7zr
python3 measure.py --fetch     # downloads the three files below into this folder
python3 measure.py             # re-derives every number in GEOMETRY.md
```

| file | what it is | upstream |
|---|---|---|
| `T-ETH-ELite.dxf` | 2D mechanical drawing of the T-ETH-Elite | `shell/T-ETH-ELite.dxf` |
| `T-ETH-ELite.7z` | 3D model (STL inside) of the T-ETH-Elite | `shell/3D/T-ETH-ELite.7z` |
| `T-ETH-ELite-LoRa-Shield.7z` | 3D model of LilyGo's own stacking shield | `shell/3D/T-ETH-ELite-LoRa-Shield.7z` |

Upstream: [Xinyuan-LilyGO/LilyGO-T-ETH-Series](https://github.com/Xinyuan-LilyGO/LilyGO-T-ETH-Series).
### The `-view.stl` files are for looking at, not for measuring

GitHub's 3D viewer stops at 10 MB and both originals are ~10.5 MB, so the
`-view.stl` pair is decimated (209k → 75k and 211k → 64k triangles, 3.8 MB and
3.2 MB). Decimation eats thin features: the base board's view model comes out
72.500 × 49.192 × **17.703** against the original's 72.500 × 49.352 × **18.822**,
i.e. about 1.1 mm of height is simply gone. Fine for seeing the shape, useless
for dimensions. `measure.py` reads the `.7z` originals and never touches these.

Upstream is [Xinyuan-LilyGO/LilyGO-T-ETH-Series](https://github.com/Xinyuan-LilyGO/LilyGO-T-ETH-Series),
fetched 2026-09-22. The `.7z` archives are kept compressed (≈1.3 MB each);
extracted they are ~10 MB STLs, which is not worth carrying in git.

## Reproducing GEOMETRY.md

```bash
pip install --user ezdxf trimesh manifold3d py7zr
python3 measure.py            # uses the files here
python3 measure.py --fetch    # or download them first
```

It prints, straight out of the vendor files:

- the four mounting holes, from the DXF *and* independently from the 3D model,
  and again from LilyGo's own shield — three sources for the same four holes
- the 40-pin grid, recovered by sectioning the header body above its plastic so
  the pins come out as 40 separate closed regions
- the board outline, simplified enough to show the antenna notch on the base
  board and the RJ45 notch on the shield
- every part standing more than 3.5 mm off the PCB — which is where the
  RJ45-vs-header-height problem that justifies the adapter comes from

It does not write anything or edit GEOMETRY.md. Compare by eye; if a number has
drifted, GEOMETRY.md is what needs updating, and every consumer of it
(here `../../hardware/make_t1s_hat.py`; in the adapter repo also its `pcb/` and `case/`) re-runs from
constants, not from hand-copied values.

## The one thing it cannot check

The TSN Lab 10Base-T1S HAT has no published CAD. Its 58 × 49 mounting pattern
is inferred from a product photo (see GEOMETRY.md for the method and the error
bars). Nothing in the adapter's fit to the *Elite* depends on that; only the
placement of the adapter's two far holes does.

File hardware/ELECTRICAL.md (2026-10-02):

# T1S HAT — electrical design spec

Our own 10BASE-T1S board for the LilyGO T-ETH-Elite, built around a
**Microchip LAN8651** MAC-PHY. Replaces buying TSN Lab's HAT; same chip family,
same host, our schematic.

Companion to [`../mechanical/GEOMETRY.md`](../mechanical/GEOMETRY.md), which fixes the
mechanical side and is reused unchanged. This file is the electrical source of
truth: **if the KiCad files disagree with this file, this file is right.**

Every value below is quoted from Microchip DS60001734F (LAN8650/1 data sheet)
or DS60001718D (AN1718, LAN86xx Bus Interface Network reference design). No
value here is inferred or carried over from a similar part.

## Why LAN8651 and not LAN8650

Same pinout except three pins, and those three decide the whole power design:

| pin | LAN8650 | LAN8651 |
|---|---|---|
| 6, 15 | VDDC (+1.8 V core in) | DNC |
| 21 | VDDC (+1.8 V core in) | **CCOMP** |

> "Core LDO Supply Compensation — CCOMP — Internal +1.8 V LDO core
> compensation. This pin requires a 4.7 μF low ESR capacitor to the PCB ground
> plane. This pin is only on the LAN8651." — DS60001734F Table 3-8

**The LAN8651 regulates its own 1.8 V core internally.** The LAN8650 does not:
its reference schematic needs an external 1.8 V LDO plus an SS14 sequencing
diode between the rails. Choosing LAN8651 deletes a regulator, a diode, a rail
and its whole decoupling group, and leaves the board **single-supply 3.3 V**.
TSN Lab's HAT uses LAN8651 too (their device-tree overlay declares
`compatible = "microchip,lan8651"`, and the board silkscreen reads LAN8651 even
though the shop listing says LAN8650).

## Pinout — 32-VQFN 5×5 mm, 0.5 mm pitch, exposed pad = VSS

| # | name | # | name | # | name | # | name |
|---|---|---|---|---|---|---|---|
| 1 | INH | 9 | IRQ_N | 17 | VDDP | 25 | VDDAU |
| 2 | VSS | 10 | SDO | 18 | DIOA0 | 26 | RBIAS |
| 3 | VSS | 11 | CS_N | 19 | DIOA1 | 27 | XTI |
| 4 | TEST | 12 | SCLK | 20 | DIOA2 | 28 | XTO |
| 5 | VSS | 13 | SDI | 21 | **CCOMP** | 29 | VDDA |
| 6 | DNC | 14 | DIOB1 | 22 | DIOA3 | 30 | TRXP |
| 7 | VDDP | 15 | DNC | 23 | DIOA4 | 31 | TRXN |
| 8 | RESET_N | 16 | DIOB0 | 24 | WAKE_OUT | 32 | WAKE_IN |

**Exposed pad must be connected to ground.**

## Mandatory pin handling — quoted, not guessed

| pin | what the data sheet says | so |
|---|---|---|
| TEST (4) | "This pin must be connected to VDDP." | **to 3V3**, not ground. Easy to get backwards. |
| DIOB1 (14) | "reserved for Microchip test use. It is recommended that this pin is connected directly to ground." | to GND |
| DNC (6, 15) | "must be left floating externally" | no connect, no copper stub |
| WAKE_IN (32) | "When not used, this pin should be connected to VSS." | to GND (VDDAU domain) |
| WAKE_OUT (24) | "When not used, this pin should be left unconnected." | NC |
| DIOA0-4, DIOB0 | "When not used, these pins may be connected directly to ground." | all to GND (Rev C: no LEDs; the LAN8651 has no LED function) |
| RESET_N (8) | "When not used, this pin must be connected directly to VDDP." | driven from the host **plus** a 10 k pull-up to 3V3, so a floating GPIO during ESP32 boot cannot hold the PHY in reset |
| RBIAS (26) | "requires connection of a 12.4 kΩ resistor to ground… within ±1% across the entire expected operating temperature range" | **12.4 kΩ 1 %**, no substitutions |

## Power — single 3.3 V rail

3V3 comes from the 40-pin header (pins 1 and 17). No other rail on the board.

| net | pins |
|---|---|
| VDDP | 7, 17 |
| VDDA | 29 |
| VDDAU | 25 (must stay powered in sleep — here it is simply always on) |

Decoupling, per the data sheet's own layout rule — *"Place one 0.01 µF and one
0.1 µF at each power pin. The 0.01 µF must be closest to the pin."*:

- **each** of VDDP 7, VDDP 17, VDDA 29, VDDAU 25 → 0.1 µF + 0.01 µF
- one 10 µF bulk near the device, on the supply side
- **CCOMP (21) → 4.7 µF low-ESR** to ground. Required, not optional. Microchip
  asks for **"4.7 µF low ESR (metal film)"** — in the data sheet's body
  (DS60001734F, power-supply section) and in the Hardware Design Checklist
  (DS60001746D); only the pin-description table says plain "low ESR capacitor".
  A 4.7 µF metal-film part is not a practical 0805, so this board uses an **X7R**
  MLCC (Yageo CC0805KKX7R8BB475): low ESR, stable over temperature, and at 1.8 V
  with no meaningful DC-bias loss. **This is a deliberate deviation, not Microchip
  compliance.** It is accepted for the prototypes and must be checked on them:
  the 1.8 V at CCOMP (level and ripple on a scope), clean start-up and reset,
  a link that stays up over hours, and behaviour warm. If any of these fail, C4 is
  the one part to change. 0.1 µF and 0.01 µF alongside are "useful but not
  required" — include the 0.1 µF.
- Ideally two vias per decoupling cap to the plane, and caps must not share vias.

**If a real ferrite bead is fitted,** the checklist requires a local ~10 µF bulk
capacitor between the bead and the pin's decoupling. The board has no footprint
for that, so FB1–FB4 are 0 Ω links in practice; with 0 Ω links a single 10 µF on
the 3.3 V supply (C6) is exactly what the checklist asks for.

Optional, footprint-only: ferrite beads (~300 Ω @ 100 MHz, e.g. Würth
742792640, DC rating ≥2× the pin current) to island VDDA (FB1) / VDDAU (FB2) /
VDDP pin 7 (FB3) / VDDP pin 17 (FB4). The
data sheet recommends carrying the option through prototype. Populate 0 Ω.

## Clock

25.0 MHz crystal, fundamental, parallel resonant, across XTI (27) / XTO (28),
load caps **C15 = C16 = 18 pF** (data sheet allows 10–22 pF; it calls them C1/C2 — on
this board C1/C2 are the bus DC-block caps).

> "external series resistors should not be used… The device contains an internal
> ~1 MΩ resistance in parallel with the crystal amplifier… therefore an external
> resistance between XTO and XTI should not be used."

So: no series resistor, no feedback resistor. Oscillator margin should be >10
and at least 5 — a crystal with low ESR and the right CL matters here.

### The fitted part (added 2026-09-28, after LCSC sourcing)

**Y1 = YXC X322525MOB4SI, LCSC C9006**: 25.000 MHz, **CL 12 pF**, ESR 50 Ω
max, ±10 ppm at 25 °C, ±20 ppm over −40…+85 °C, SMD3225 **4-pad** (1/3
crystal, 2/4 lid → GND). JLCPCB basic part, 167 k in JLC's stock on 2026-10-01.

Two corrections to what the board had before:

- **Package.** The first layout used a 3.2 × 1.5 mm 2-pad land. No 25 MHz
  crystal is made in that package (3215 is the 32.768 kHz watch-crystal size),
  so it matched no orderable part. The land is now KiCad's
  `Crystal_SMD_3225-4Pin_3.2x2.5mm`.
- **CL 12 pF, with the 18 pF load caps kept.** The load a crystal sees is
  C15·C16/(C15+C16) + C_stray = 18/2 + ~3 pF ≈ **12 pF**. A CL 18 pF crystal on
  18 pF caps would therefore run fast; it would need ~30 pF caps instead. The
  data sheet's 18 pF figure is kept for C15/C16, and the crystal is chosen to
  match it.

**Oscillator margin.** The critical transconductance for this crystal is

  gm_crit = 4 · ESR · (2πf)² · (C0 + CL)²
          = 4 · 50 Ω · (2π · 25 MHz)² · (3 pF + 12 pF)² ≈ **1.1 mA/V**

where C0 ≤ 3 pF is taken from YXC's YSX321SL family sheet. The LAN8651's own
oscillator transconductance is in the data sheet: **DS60001734F §8.6 gives
18.2 mS (nominal)**. The margin is therefore 18.2 / 1.1 ≈ **16**, above both
the ≥5 minimum and the >10 target. (An earlier version of this file said
Microchip does not publish the gm; that was wrong.) For comparison, a CL 18
part would need about twice as much (2.2 mA/V), a margin of ≈8. 18.2 mS is a
nominal figure, not a guaranteed minimum, so it is still worth a check on the
first board: add series resistance until oscillation stops; that resistance
divided by ESR is the measured margin.

**Frequency error, estimated.** ±10 ppm tolerance + ±20 ppm over temperature,
plus pulling from the stray-capacitance guess. At ~11 ppm per pF of load error
for a typical 5 fF motional capacitance, a ±2 pF error in the 3 pF guess
costs ±22 ppm. The worst case is ≈ 52 ppm, inside Ethernet's ±100 ppm.

## Host interface — matches TSN Lab's device-tree overlay on purpose

Their overlay (`lan8650-overlay-rpi4.dts`) declares `spi0`, `reg = <0>` (CE0),
`interrupts = <23 …>`. Wiring to the same header pins means their SDK and the
mainline `microchip,lan8651` driver both work unmodified if this board is ever
put on a Pi, and costs nothing on the ESP32 side.

| LAN8651 | header pin | RPi name | ESP32-S3 on the Elite |
|---|---|---|---|
| SDI (13) | 19 | GPIO10 / SPI0 MOSI | **IO11** SPI_MOSI (shared with the TF card) |
| SDO (10) | 21 | GPIO9 / SPI0 MISO | **IO9** SPI_MISO (shared with the TF card) |
| SCLK (12) | 23 | GPIO11 / SPI0 SCLK | **IO10** SPI_SCLK (shared with the TF card) |
| CS_N (11) | 24 | GPIO8 / SPI0 CE0 | **IO0 = BOOT strap** — see below; 10 k pull-up to 3V3 |
| IRQ_N (9) | 16 | GPIO23 | **IO39**; 10 k pull-up to 3V3 |
| RESET_N (8) | 15 | GPIO22 | **IO42**; 10 k pull-up to 3V3 |

SPI clock up to 25 MHz. Protocol is OPEN Alliance TC6.

The ESP32 column is read off LilyGo's own schematic (`schematic/T-ETH-ELite.pdf`
in `Xinyuan-LilyGO/LilyGO-T-ETH-Series`, sheet 2, connector J1), and it is
mirrored in [`firmware/t1s_node/pins.h`](../firmware/t1s_node/pins.h). Two
consequences of it:

- **CS_N lands on IO0, the ESP32-S3's BOOT strap.** That is where a Pi puts
  CE0 and it works: the strap wants IO0 high at reset, both the Elite (its R1)
  and this board (R5) pull it up, and CS_N is an input on the LAN8651, so
  nothing here can drag it low. But pressing the Elite's BOOT button on a
  running node asserts CS_N mid-transaction. The driver catches that as a
  parity error; do not do it on a live bus. Flashing is unaffected.
- **MOSI/MISO/SCLK are the Elite's general SPI, shared with its TF card**
  (card CS = IO12). Firmware holds IO12 high. The Elite's W5500 is on a
  different bus (IO47/21/48/45), so the two Ethernet interfaces can run
  together.

We deliberately do **not** copy TSN Lab's FXL6408 I²C GPIO expander (their
GPIO24 interrupt) or their rotary node-ID switch: the PLCA node ID is a
register write, so it belongs in firmware, and dropping the expander removes a
part, an I²C bus and an interrupt line.

## Bus Interface Network — TRXP (30) / TRXN (31) to the cable

Order from the chip outward, per AN1718:

```
TRXP/TRXN ─ CMC(L1) ─ C1/C2 100nF ─ [R1/R2 termination] ─ [ESD] ─ CN1
```

| ref | value | note |
|---|---|---|
| L1 | common-mode choke, **200 µH @ 100 kHz — TDK ACT1210L-201-2P-TL00** (LCSC C131444), ACT1210 package | **always populated.** AN1718's examples are ACT1210D-131 (130 µH), ACT1210E-241 / Murata DLW32MH241MX2 (240 µH); the note leaves the choice to the application. 200 µH sits inside that span, is AEC-Q200 and was the one in stock: a **prototype-selected alternative, EMC validation pending**. The land fits all three. |
| C1, C2 | 0.1 µF, 100 V, 0805 | DC block / galvanic isolation. **Always populated, on every node.** |
| R1, R2 | **49.9 Ω 1 % 1206** for an END-OF-BUS node — AN1718 lists **1 W**; the part ordered is **0.75 W** (C4014562), a lab-prototype substitution because no 1 W 1206 was stocked (ORDERING.md). Fit a 1 W part (Susumu HRG3216P, Vishay PHP01206) by hand for anything past the bench.<br>**1.5 kΩ 1 % 1206** for an interior DROP node | footprints fitted, **DNP by default** — stuff per where this node sits on the bus |
| R3 | 100 kΩ 1 % 0805 + C3 | common-mode termination (drop node), per AN1718's drop-node topology |
| MOV1/2 | TDK AVRH10C221KT1R5YA8 or Panasonic EZA-EG3W11AV | ESD, optional, footprint by the connector |
| CN1 | 4-pin 3.81 mm pluggable terminal block | P_in/N_in + P_out/N_out, the two P's and the two N's shorted on board so the node taps a daisy chain |

**No pin header on the bus.** AN1718 wants ESD and termination in-line with
stubs minimised; a jumper header on T1S is a stub. Termination is selected by
which resistors get stuffed, marked on silkscreen, not by a removable jumper.

## Status LED — none on this board (Rev C)

The LAN8651 has **no LED function**: PADCTRL (0x88) A0SEL/A1SEL select only event
capture (input) or event generator (output) for DIOA0/1 (DS60001734F §11.6.3). Rev B
put LEDs on them that firmware could never have driven with PLCA state; Rev C ties
**DIOA0…4 and DIOB0/1 to ground**, as the data sheet allows for unused pins.

Status is shown on the **Elite's own LED (IO38)** by firmware, from PLCA_STS.PST
(MMS 4, 0xCA03): solid = beacons seen (or link up under CSMA/CD), fast blink = PLCA
on but no beacons, slow blink = no link.

## Board rules

- **4-layer, 1.6 mm, JLCPCB JLC04161H-7628 (since Rev B, 2026-09-28; unchanged in Rev C).**
  F.Cu signals and parts / In1.Cu solid GND / In2.Cu +3V3 plane / B.Cu the
  three SPI escapes that cannot stay on top, plus a GND pour. AN1718's 50 Ω
  single-ended TRXP/TRXN is **met by construction**: over 0.2104 mm of 7628
  prepreg (εr 4.4), a 0.35 mm microstrip is 50.1 Ω (IPC-2141), and every bus
  trace from the choke to CN1 is 0.35 mm, asserted by the generator. Rev A
  was 2-layer and argued its way out of this; that argument is in git history.
  It was not worth the cost: an 84 mm VDDP detour, a 0 Ω jumper, a signal
  running between resistor pads, and one via per decoupling cap.
- **In1.Cu carries no tracks at all** (asserted). It is the reference for
  every F.Cu signal, and the T1S pair runs over it unbroken except at the
  choke void AN1718 asks for.
- **Every 3V3 connection is a via into In2.Cu** beside its pad. There is no
  3V3 trace anywhere on the board.
- **Each VDDP pin is its own ferrite-option island** (pin 7 + TEST via FB3,
  pin 17 via FB4), with its 0.01 µF and 0.1 µF directly at the pin.
- **TRXP/TRXN short, length-matched, symmetric, no vias.** Let this drive
  placement: the LAN8651 goes near the bus connector, ahead of tidiness.
- **All-layer void under the common-mode choke**, per AN1718, to stop coupling
  from its core.
- ESD parts and coupling caps close to the connector; minimise stubs on the bus.
- Exposed pad stitched to the ground plane with a via array.
- **Antenna keepout:** the Elite's ESP32-S3-WROOM antenna sits under this board
  at x 58…66.22, y 22…44 (its own PCB is cut away at x 59.84…66.19,
  y 23.93…42.22). A ground plane above a PCB antenna detunes it, so **no copper
  on any layer** in that window: all four layers, planes included, are cut
  there by one rule area, and the generator checks every filled polygon.

## Mechanical — inherited, with one deliberate departure

From [`../mechanical/GEOMETRY.md`](../mechanical/GEOMETRY.md), unchanged:

- outline 66.22 × 49.19, R3 corners
- four asymmetric mounting holes (3.33, 4.63) (61.33, 4.63) (2.98, 46.23)
  (63.23, 46.20) — 58.00 apart at the bottom, 60.25 at the top, self-keying
- 2×20 header grid, x = 8.196 + 2.54·k (k = 0…19), y = 3.360 and 5.900

**Departure: no RJ45 notch. The outline is a plain rectangle.** GEOMETRY.md's
notch exists for a board sitting ~13 mm up, which would foul the Elite's
15.97 mm RJ45. This board is instead lifted clear of the jack on a taller
riser, so nothing has to be cut away — and that matters more than convenience
here, because the notch was the largest interruption in the bottom-side ground
pour, right where the T1S pair and its choke want a clean reference.

### The riser is two-stage, and this is easy to get wrong

The Elite's header pins are only **9.30 mm** tall. A single tall stacking
header does *not* work: its contacts sit near the top of the barrel, so with a
~17 mm barrel the Elite's pins reach barely halfway and never touch. What
works is two stages — a 2×20 stacking riser onto the Elite's pins, presenting
longer pins, then this board's socket onto those. Put that in the BOM notes,
not just here.

Resulting height above the Elite PCB: **≈23 mm (calculated)**, set by the riser. Nothing
in the design may depend on an exact figure.

The Elite carries an on-board PoE front end — RJ45 `HY931147C` tapping
POWER+/− into an **SDaPo DP9900M-5V** PD module (5 V, 9 W @ 70 °C), with a
polyfuse, an SMAJ58A TVS and 4.7 nF/2 kV isolation caps. That module is **not
in LilyGo's 3D model** (it does not appear among the parts over 3.5 mm) and
SDaPo's datasheet carries no dimensioned drawing, so CAD cannot settle its
height. Reported from the physical board: **it stands about level with the
RJ45**, so the RJ45's measured 15.97 mm remains the height to clear and the
riser covers both. Source is direct observation of the real hardware, not a
document — if a future board revision changes the PD module, re-check it.

### Bottom side is usable

At ~23 mm the underside of this board has 14+ mm of clearance everywhere
except over the RJ45 footprint (x −5.18…16.42, y 10.50…28.90), where it is
much less. Prefer the bottom for anything bulky. A later radar variant will
want that space.

## Not decided here

- Radar variant (A121 / XM125) — a derivative of this board, specified
  separately once this one links.
- PLCA node count, node IDs, coordinator election: firmware, not hardware.

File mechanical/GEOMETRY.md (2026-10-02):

# Verified geometry — the single source of truth for this board

> **Correction, 2026-09-28: header pin numbering.** This file originally said
> nothing about which end is pin 1, and the boards inferred it as the low-x
> end on the edge row. That was the exact 180° opposite. LilyGo's own pin-map
> image of the Elite (top view) shows 3V3 (pin 1) at the USB-C end on the inner
> column. That orientation of the photo is pinned down twice by numbers in this
> file: the 58.00 mm hole pair is the header side, and the per-end hole offsets
> (1.9 mm at one end, 0.35 mm at the other) match the photo with USB-C at high
> x; the WROOM antenna, at the USB-C end in the photo, is where the keepout
> sits (x 58…66). The grid positions themselves were always right.
>
> Carried over on 2026-09-28 from an earlier adapter project (a Pi-HAT carrier
> for the Elite), where it was first written. The T1S HAT uses its outline,
> mounting holes and 2×20 grid as-is. The adapter's own outline, RJ45 notch and
> six-hole pattern do **not** apply to this board and now live in
> [`legacy_adapter_geometry.md`](legacy_adapter_geometry.md); the last section
> below is the T1S HAT as built. `reference/measure.py` re-derives
> every number from LilyGo's own files, in `reference/`.

Every number below was measured from a primary source and cross-checked against
at least one independent one. Nothing here is estimated, rounded from a photo,
or carried over from the Raspberry Pi HAT spec by assumption. **If the KiCad
files and this file ever disagree, this file is right and the board is wrong.**

Frame used throughout: **T-ETH-Elite top view, origin = its PCB bottom-left
corner, +x right, +y up.** All units mm.

## Sources

| tag | what | where |
|---|---|---|
| `DXF` | LilyGo 2D mechanical DXF | `shell/T-ETH-ELite.dxf`, github.com/Xinyuan-LilyGO/LilyGO-T-ETH-Series |
| `CAD` | LilyGo 3D model of the base board | `shell/3D/T-ETH-ELite.7z` → `T-ETH-ELite.stl`, same repo |
| `SHLD` | LilyGo 3D model of their own LoRa shield | `shell/3D/T-ETH-ELite-LoRa-Shield.7z`, same repo |
| `RIG` | a laser-cut acrylic mounting plate generated from the same hole set, **physically validated**: a real board was offered up to the plate and sat centred on its holes |

## T-ETH-Elite base board

| item | value | source |
|---|---|---|
| PCB outline | 66.191 × 49.192, R3 corners | `CAD` slab; `DXF` agrees |
| antenna keepout notch (right edge) | x 59.84…66.19, y 23.93…42.22 | `CAD` outline |
| PCB thickness | 1.575 (≈1.6) | `CAD` |

### Mounting holes — asymmetric, NOT a rectangle

| # | `DXF` | `CAD` | `SHLD` | **use this** (`RIG`, physically validated) |
|---|---|---|---|---|
| bottom-left | (3.327, 4.628) | (3.339, 4.630) | (3.333, 4.636) | **(3.33, 4.63)** |
| bottom-right | (61.367, 4.638) | (61.339, 4.630) | (61.433, 4.636) | **(61.33, 4.63)** |
| top-left | (2.987, 46.288) | (2.991, 46.228) | (3.004, 46.228) | **(2.98, 46.23)** |
| top-right | (63.227, 46.198) | (63.241, 46.198) | (63.254, 46.198) | **(63.23, 46.20)** |

Bottom pair spacing **58.00**, top pair **60.25** — the asymmetry is real design,
not a CAD slip; three independent files agree to <0.1. PCB hole Ø2.500 on the
board itself; M2.5 hardware.

A useful consequence: **the pattern is self-keying.** 58.00 ≠ 60.25 means a board on
this hole set physically cannot be bolted on rotated 180°.

### 40-pin GPIO header

| item | value | source |
|---|---|---|
| pin grid | 20 cols × 2 rows, 2.54 pitch | `CAD`, sectioned above the plastic |
| column x | 8.196 + 2.54·k, k = 0…19 → 8.196 … 56.456 | `CAD` |
| row y | **3.360** and **5.900** | `CAD` |
| **pin numbering** | **pin 1 = (56.456, 5.900)**: the USB-C (high-x) end, on the **inner** row. Odd pins run along y 5.900 toward low x, even pins (5V, 5V, GND …) along the board-edge row y 3.360. Pin 39 = (8.196, 5.900), pin 40 = (8.196, 3.360) | `IMG` + cross-check |
| plastic body | x 6.926…57.726 (=50.800), y 0.860…8.399 | `CAD` |
| pin tip height | z = 10.10, i.e. **9.30 above the PCB** | `CAD` |

Internal consistency check that ties the two datasets together: the pin field is
centred at x 32.326 against the bottom hole pair's centre 32.33, and the rows sit
at 4.63 ± 1.27 — exactly straddling the bottom holes' y. That is the Raspberry Pi
header-to-hole relationship, reproduced by LilyGo.

### Component heights above the PCB — what a stacked board must clear

Heights below are LilyGo CAD z, in which the PCB's **top face is at 0.80**
(the 1.575 slab is centred on z=0). Subtract 0.80 for height above the PCB
surface. The comparison that matters is a difference, so it holds in either
frame.

| part | top (CAD z) | = above PCB | footprint |
|---|---|---|---|
| **RJ45 (with magnetics)** | **15.97** | **15.17** | x −5.18…16.42 (hangs 5.18 off the left edge), y 10.50…28.90 |
| 40-pin header pins | 10.10 | 9.30 | x 6.93…57.73, y 0.86…8.40 |
| two parts at the far edge (BOOT/RST) | 4.00 | 3.20 | x 41.48…45.98 and 52.10…56.60, y 45.85…49.35 |
| ESP32-S3-WROOM-1 | 3.90 | 3.10 | x 40.47…65.97, y 24.07…42.08 |

**The RJ45 is 5.87 mm taller than the header pins.** Anything that plugs onto
that header and spans the left half of the board fouls it unless it is notched
**or** lifted clear of 15.97 altogether.

Stated precisely, because an earlier draft of this file overstated it: a tall
enough stacking header alone would lift a HAT above the RJ45 with no adapter at
all. What that does *not* give you is anywhere to put the HAT's far mounting
pair, which lands at y = 53.63, past the Elite's own 49.19 edge — so the HAT
would hang off two screws at the connector end. On a board carrying a
lever-actuated terminal block that is the difference between a fixture and a
wobble. (That was the adapter's reason to exist. The T1S HAT answers it differently: it
keeps the Elite's own four holes and outline, so all four standoffs land on the
Elite — see the last section.)

## LilyGo's own LoRa shield — the reference design for stacking on this board

| item | value |
|---|---|
| outline | same 66.22 × 49.19, R3 |
| **RJ45 notch** | x 0…16.87, y 11.25…28.45 (cut into the left edge) |
| mounting holes | the same 4 asymmetric holes, within 0.1 of the base board |
| connector | one 2×20 **stacking header**: socket barrel ~13.0 below the shield PCB, pins reaching 9.30 above it — one part, one set of 40 holes |

So LilyGo stack their shields at ~13 mm above the base PCB and clear the RJ45
with a notch. The T1S HAT does not: it is lifted above the jack instead.

## Therefore — the T1S HAT (Rev B, unchanged in Rev C)

| item | value |
|---|---|
| outline | 0…66.22 × 0…**49.19**, R3 corners — the Elite's own outline |
| RJ45 notch | **none** — the board sits above the jack on a riser |
| mounting holes | **4**, Ø2.75 NPTH (M2.5 free fit), the Elite's own set: (3.33, 4.63) (61.33, 4.63) (2.98, 46.23) (63.23, 46.20) |
| 2×20 socket | on the grid above, pin 1 = (56.456, 5.900) |
| antenna keepout | x 58.00…66.22, y 22.00…44.00, all layers, nothing placed |
| stack height | HAT underside ≈**23** above the Elite PCB — **calculated, not measured** |

Why no notch, and the two-stage riser that sets the height, are in
[`../hardware/ELECTRICAL.md`](../hardware/ELECTRICAL.md) ("Mechanical"). The
23 mm figure is the one mechanical number here not taken from a primary source:
check it, and the clearance over the RJ45 and PoE module, with a real Elite,
riser and socket before trusting it.

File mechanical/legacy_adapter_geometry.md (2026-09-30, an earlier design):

# Legacy: the Pi-HAT adapter's geometry

**Not this board.** Kept from the earlier adapter project (a carrier that put a
Raspberry-Pi-format HAT on the Elite) for the record. Its 57.20 mm outline, RJ45
notch and six holes are *not* the T1S HAT's; for that, see
[`GEOMETRY.md`](GEOMETRY.md), whose Elite measurements both designs share.

## The TSN Lab 10Base-T1S HAT (the board this adapter exists to carry)

Silkscreen on the product photo reads **`10BASE-T1S HAT / LAN8651 / For RPi /
TSNlab+Ethercrafts`** — note **LAN8651**, not the LAN8650 the devicemart listing
states.

Measured off the product photo, scaled by the known 48.26 mm pin-row span:

| item | value | confidence |
|---|---|---|
| mounting holes | a **rectangle**, ratio 0.852 vs the Pi spec's 49/58 = 0.845 | good — it is a standard Pi 58 × 49 pattern |
| board | ≈63 × 55, i.e. a normal-size HAT | photo-derived, ±2 |
| edge inset of holes | ≈3.5 | photo-derived |

Photo-derived numbers are **not** used for anything this board's correctness
depends on. They are used only to justify one decision: that placing the two far
holes on the Pi spec's 49 mm offset is the right call. The listing's "57×75×23"
does not match the photo and is assumed to be packaging.

## Therefore — this adapter

Outline 0…66.22 × 0…**57.20**, R3 corners. Same width as the base board;
extended +8.0 in y past it so it can carry the HAT's far mounting holes, which
land beyond the base board's own edge.

**RJ45 notch: x 0…17.40, y 10.00…29.40** — deliberately ~0.5 larger all round
than the RJ45's measured envelope, rather than a copy of LilyGo's slightly
tighter 16.87/11.25/28.45. The notch region is empty board on this design, so
the extra clearance costs nothing.

### Holes — 6, all Ø2.75 (M2.5 free fit)

| ref | position | serves |
|---|---|---|
| H1 | (3.33, 4.63) | T-ETH-Elite bottom-left **and** HAT near-left |
| H2 | (61.33, 4.63) | T-ETH-Elite bottom-right **and** HAT near-right |
| H3 | (2.98, 46.23) | T-ETH-Elite top-left |
| H4 | (63.23, 46.20) | T-ETH-Elite top-right |
| H5 | (3.33, 53.63) | HAT far-left |
| H6 | (61.33, 53.63) | HAT far-right |

H1/H2 are shared on purpose. Deriving the Pi near-hole positions in this frame
from the header (centre 32.326 ± 29.0, y = the header centre 4.63) gives
(3.326, 4.63) and (61.326, 4.63) — the T-ETH-Elite's own bottom holes to within
**0.005 mm**. They are the same holes; one pair is drilled, not two.

H5/H6 are H1/H2 offset by the Pi spec's +49.0 in y.

### Connector

One 2×20 THT stacking header, pins on the grid above: x = 8.196 + 2.54·k
(k = 0…19), y = 3.360 and 5.900. Plated through-holes with annular rings both
sides — the solder joint is what mechanically anchors the stack.

No traces. The signal path is the stacking header's own pin, straight through
from the socket below to the exposed pin above; the board contributes nothing
electrical and pin-to-pin identity is guaranteed by the part, not by copper.
Every pad is an isolated net by design.

### Stack-up that results

```
   TSN Lab 10Base-T1S HAT (LAN8651)
        ↑ plugs onto the pins protruding above the adapter
   ── this adapter ──                      ≈13 above the Elite PCB
        ↑ stacking-header socket swallows the Elite's 9.30 pins
        ↑ RJ45 (15.97) passes up through the notch
   LilyGO T-ETH-Elite (ESP32-S3)
```

Standoffs: Elite → adapter ≈13 (set by the chosen stacking header's barrel);
adapter → HAT set by that header's above-board pin length. Both are properties
of the header part, so pick the standoffs after picking the header, not before.

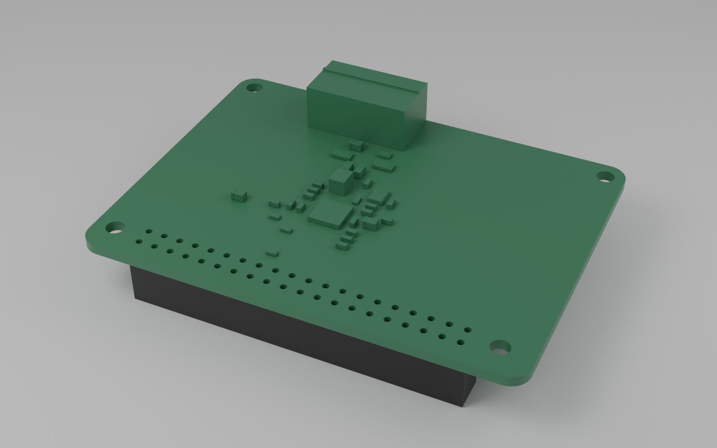
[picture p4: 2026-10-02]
mechanical/model/render-hat.png

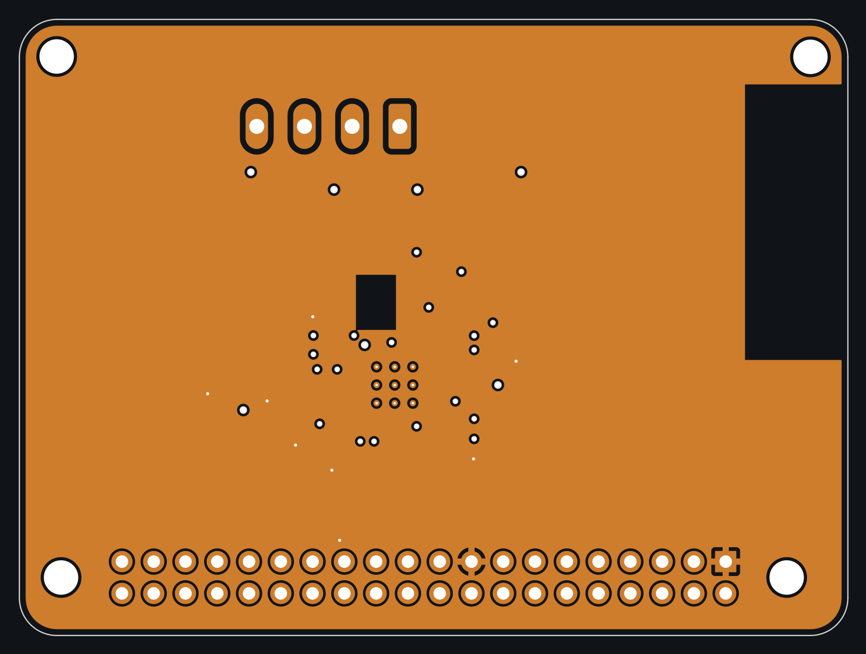
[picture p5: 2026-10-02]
hardware/preview-in2.png

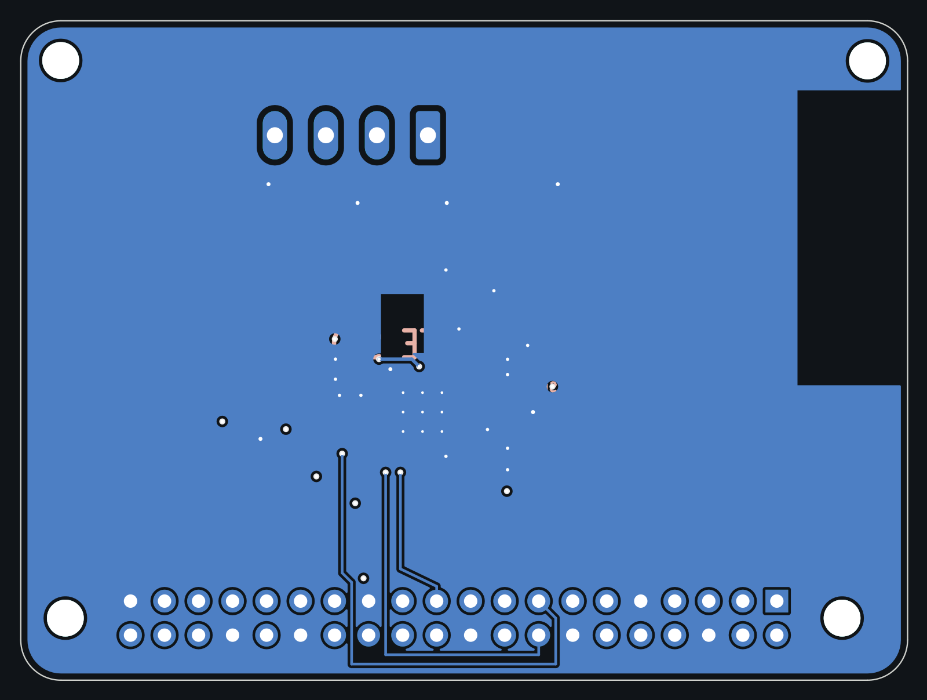
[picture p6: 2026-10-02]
hardware/preview-back.png

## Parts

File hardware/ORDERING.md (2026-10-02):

# Ordering the T1S HAT at JLCPCB

What to upload, what to tick, and the three things to look at before paying.
Stock figures are JLC's assembly warehouse, re-checked on **2026-10-01**.

**For the Rev C prototype run (2–3 boards, END/END link): upload
`gerbers/t1s_hat_gerbers.zip`, then `jlcpcb/end/bom_jlc.csv` and
`jlcpcb/end/cpl_jlc.csv`.** That variant has R1/R2 = 49R9 fitted, which is
what a two-node bench needs. The sections below explain each choice.

## 1. PCB

Upload **`gerbers/t1s_hat_gerbers.zip`** (10 gerber layers, 4 of them copper,
plus separate PTH/NPTH Excellon and a job file).

| option | value | why |
|---|---|---|
| Layers | **4** | Since Rev B. Signal / GND / 3V3 / signal, see `ELECTRICAL.md` "Board rules" |
| Stack-up | **JLC04161H-7628** | the one the board file is built for: 0.2104 mm prepreg to each plane |
| Impedance control | **yes**, 50 Ω single-ended on L1 ref L2, 0.35 mm | the T1S pair (CMC_P/N, BUS_P/N). Optional; without it the pair still sits at ≈50 Ω by design, JLC just doesn't test it |
| Dimensions | 66.22 × 49.19 mm (JLC reads it from Edge.Cuts) | |
| Thickness | **1.6 mm** | |
| Material | FR-4 | |
| Outer / inner copper | 1 oz / 0.5 oz | JLC's default for that stack-up |
| Min track / space | 0.15 / 0.20 mm | 0.15 mm tracks (SPI escapes), 0.20 mm clearance from the net classes; the bus pair keeps 0.45 mm to other nets (`t1s_hat.kicad_dru`); inside JLC standard |
| Min hole | 0.20 mm | U1's exposed-pad thermal vias |
| Surface finish | **ENIG** recommended, lead-free HASL works | 0.5 mm-pitch QFN and 0402 lands sit flatter on ENIG |
| Via covering | tented | |
| Remove order number | "specify a location" (no free spot; or pay for removal) | |

## 2. Assembly (PCBA), top side only

Upload the BOM and CPL of one variant — **`jlcpcb/end/`** (R1/R2 49R9,
end-of-bus nodes: the prototype run), `jlcpcb/drop/` (R1/R2 1K5, interior
nodes) or `jlcpcb/` (R1/R2 left unfitted). All are written by
`make_t1s_hat.py` in JLCPCB's own column names. J1 and the MOVs are left out
on purpose (see section 3).

**The CPL is in JLC's footprint frame, not KiCad's**, and
`check_jlc_cpl.py` proves it: it fetches the EasyEDA footprint JLC places for
every LCSC number, puts it where the CPL says, and checks each pad lands on
ours (0 parts off, all three variants, 2026-09-30). Two parts needed
correcting against a plain KiCad export — without this, both would have been
placed wrong:

- **L1** — EasyEDA draws the ACT1210 turned 90° from ours: CPL says 0°, not
  KiCad's 90°. (EasyEDA also numbers its pads in mirror order; the windings
  are straight across in both, so each still joins TRX to CMC on its own line.)
- **CN1** — EasyEDA's origin is the body centre, KiCad's is pin 1: the CPL
  gives the pad centroid, 5.715 mm from KiCad's origin.

Stock = JLC's assembly warehouse, read 2026-10-01 (all 15 lines of the `end/` BOM in stock).

| ref | part | LCSC | JLC class | stock |
|---|---|---|---|---|
| U1 | Microchip LAN8651B1-E/LMX, VQFN-32 5×5 | C22386973 | extended | **199: check first** |
| Y1 | YXC X322525MOB4SI 25 MHz CL12 3225-4P | C9006 | basic | 167 k |
| L1 | TDK ACT1210L-201-2P-TL00 CMC | C131444 | extended | 3.5 k |
| CN1 | Phoenix 1803293 MC 1,5/4-G-3,81 (THT) | C480536 | extended | 2.4 k |
| R7 | 12k4 1 % 0603 | C22865 | extended (no basic exists) | 224 k |
| R1, R2 (`end/`) | Vishay CRCW120649R9FKEAHP 49R9 1 % 1206 0.75 W | C4014562 | extended | 6.2 k |
| C1–C3 | 100 nF 100 V X7R 0805 | C28233 | basic | |
| C4 | 4.7 µF 25 V **X7R** 0805 (CCOMP) — **PROTOTYPE_X7R**: Microchip asks for metal film, see ELECTRICAL.md | C354262 | extended | 581 k |
| C6 | 10 µF 25 V X5R 0805 | C15850 | basic | |
| C5 C7 C9 C11 C13 | 100 nF 0603 | C14663 | basic | |
| C8 C10 C12 C14 | 10 nF 0603 | C57112 | basic | |
| C15 C16 | 18 pF C0G 0603 | C1647 | basic | |
| R3 | 100 k 1 % 0805 | C149504 | basic | |
| R4–R6 | 10 k 0603 | C25804 | basic | |
| FB1–FB4 | 0 Ω 0603 (ferrite-bead option) | C21189 | basic | |

**6 extended parts with `end/` or `drop/`** (U1, L1, CN1, R7, C4 and R1/R2), 5 with the unfitted `jlcpcb/` BOM; Rev C dropped the two LEDs. Expect one setup fee per extended part. CN1 is through-hole:
either let JLC fit it (THT assembly fee) or delete its line and hand-solder it.

**Before confirming, still look at JLC's placement preview for these** —
`check_jlc_cpl.py` checks footprints, not the reel orientation JLC's
engineers apply:

1. **U1 pin 1.** The silkscreen dot/chamfer on the QFN has to match the
   part's pin-1 mark. If it is off by 90° or 180°, fix it in the preview (JLC
   lets you rotate there).
2. **Y1.** Pads 1 and 3 have to be the crystal and 2/4 the lid. The 3225-4P
   orientation is symmetric, so a 90° error would put the crystal across the
   lid pads.

## 3. Not assembled by JLC: order separately and hand-solder

| what | part | note |
|---|---|---|
| J1: 2×20 female socket, 2.54 mm | BOOMELE 2.54-2*20P, LCSC **C5124634** (8.5 mm body, 3.1 mm tail) | **The body goes on the BOTTOM of this board**, facing the riser; solder from the top. This is why it is not in the CPL: a top-side placement would be upside down in the stack. |
| Riser: 2×20 stacking header (PC104 style) | BOOMELE, LCSC **C35165** (8.3 mm body, 12.3 mm pins) | Plugs onto the Elite's own pins (female side down); its long pins go up into J1. |
| Bus plug for CN1 | Phoenix 1803594, LCSC **C480512** (low stock, 128), or clone Kefa KF2EDGK-3.81-4P **C440860** | the clone mates with the Phoenix header |
| M2.5 standoffs × 4 | length = measured stack height | see below |

**Stack height, calculated, not measured:** riser body 8.3 mm + the ~6 mm of
its pins that J1 swallows + J1's 8.5 mm body ≈ **23 mm** from the Elite's PCB
to this board's underside. That is more than the 18–20 mm the README first
assumed, and nothing on the board depends on it. If you want it lower, trim
the riser pins. Buy standoffs after the stack is assembled and measured.

## 4. Termination: decide before ordering, or leave DNP and hand-fit

R1/R2 ship unfitted. Where the node sits on the bus decides them:

| node position | R1, R2 | LCSC |
|---|---|---|
| **end of the bus** (a 2-node bench is two end nodes) | 49R9 1 % 1206, ≥0.5 W | C4014562 (0.75 W) |
| interior drop node | 1K5 1 % 1206 | C26030 |

The data sheet's "1 W" 49R9 exists in 1206 (Susumu HRG3216P, Vishay PHP01206)
but had **zero stock** anywhere at JLC on 2026-09-28. The 0.75 W part is what
can be bought. Dissipation at 10BASE-T1S levels is milliwatts, so 1 W is
margin, not need.

To have JLC fit them, upload the `jlcpcb/end/` or `jlcpcb/drop/` variant
instead of `jlcpcb/`: it is the same BOM/CPL with the R1/R2 lines added.

## 5. For an 8-node bus

Eight nodes on one bus means **two end nodes (49R9) and six drop nodes
(1K5, per `ELECTRICAL.md`)**. Order 10 boards and fit R1/R2 by hand. That is simpler than two
BOM variants and leaves spares. At 199 in JLC's stock (2026-10-01), U1 is the only part that
limits the order quantity.

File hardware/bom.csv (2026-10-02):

Comment | Designator | Footprint | Quantity | Populate | Description | LCSC
100nF/100V | C1 | Capacitor_SMD:C_0805_2012Metric | 1 | fit | AC coupling / galvanic isolation, bus P. ALWAYS FITTED (AN1718) | C28233
10nF | C10 | Capacitor_SMD:C_0603_1608Metric | 1 | fit | VDDP (pin 17) decoupling, 0.01 uF - closest to the pin | C57112
100nF | C11 | Capacitor_SMD:C_0603_1608Metric | 1 | fit | VDDA (pin 29) decoupling, 0.1 uF | C14663
10nF | C12 | Capacitor_SMD:C_0603_1608Metric | 1 | fit | VDDA (pin 29) decoupling, 0.01 uF - closest to the pin | C57112
100nF | C13 | Capacitor_SMD:C_0603_1608Metric | 1 | fit | VDDAU (pin 25) decoupling, 0.1 uF | C14663
10nF | C14 | Capacitor_SMD:C_0603_1608Metric | 1 | fit | VDDAU (pin 25) decoupling, 0.01 uF - closest to the pin | C57112
18pF | C15 | Capacitor_SMD:C_0603_1608Metric | 1 | fit | Crystal load capacitor C1 (data sheet: C1 = C2 = 18 pF) | C1647
18pF | C16 | Capacitor_SMD:C_0603_1608Metric | 1 | fit | Crystal load capacitor C2 (data sheet: C1 = C2 = 18 pF) | C1647
100nF/100V | C2 | Capacitor_SMD:C_0805_2012Metric | 1 | fit | AC coupling / galvanic isolation, bus N. ALWAYS FITTED (AN1718) | C28233
100nF/100V | C3 | Capacitor_SMD:C_0805_2012Metric | 1 | fit | Common-mode termination, centre tap to ground (AN1718 C3) | C28233
4.7uF X7R | C4 | Capacitor_SMD:C_0805_2012Metric | 1 | fit | CCOMP: internal +1.8 V core LDO compensation. REQUIRED, low ESR, to the ground plane (LAN8651 only). Microchip asks for metal film; X7R MLCC here is a prototype deviation, see ELECTRICAL.md. | C354262
100nF | C5 | Capacitor_SMD:C_0603_1608Metric | 1 | fit | CCOMP support capacitor (data sheet: useful, not required) | C14663
10uF | C6 | Capacitor_SMD:C_0805_2012Metric | 1 | fit | Bulk decoupling on the 3.3 V supply side | C15850
100nF | C7 | Capacitor_SMD:C_0603_1608Metric | 1 | fit | VDDP (pin 7) decoupling, 0.1 uF | C14663
10nF | C8 | Capacitor_SMD:C_0603_1608Metric | 1 | fit | VDDP (pin 7) decoupling, 0.01 uF - closest to the pin | C57112
100nF | C9 | Capacitor_SMD:C_0603_1608Metric | 1 | fit | VDDP (pin 17) decoupling, 0.1 uF | C14663
T1S BUS P N N P | CN1 | Connector_Phoenix_MC:PhoenixContact_MC_1,5_4-G-3.81_1x04_P3.81mm_Horizontal | 1 | fit | MDI connector, 4-pin 3.81 mm pluggable terminal block. Pins 1..4 = P N N P; the two P and the two N are shorted on board so the node taps a daisy chain. | C480536
0R (FB opt.) | FB1 | Inductor_SMD:L_0603_1608Metric | 1 | fit | VDDA supply island option: 0 ohm fitted. A real bead needs a local 10 uF after it (DS60001746D); may be replaced by a ~300 ohm @ 100 MHz bead (e.g. Wuerth 742792640). | C21189
0R (FB opt.) | FB2 | Inductor_SMD:L_0603_1608Metric | 1 | fit | VDDAU supply island option: 0 ohm fitted. A real bead needs a local 10 uF after it (DS60001746D). | C21189
0R (FB opt.) | FB3 | Inductor_SMD:L_0603_1608Metric | 1 | fit | VDDP (pin 7) supply island option: 0 ohm fitted. A real bead needs a local 10 uF after it (DS60001746D). | C21189
0R (FB opt.) | FB4 | Inductor_SMD:L_0603_1608Metric | 1 | fit | VDDP (pin 17) supply island option: 0 ohm fitted. A real bead needs a local 10 uF after it (DS60001746D). | C21189
2x20 socket (riser stack) | J1 | Connector_PinHeader_2.54mm:PinHeader_2x20_P2.54mm_Vertical | 1 | fit | 2x20 2.54 mm THT socket; mates with the riser that plugs onto the T-ETH-Elite's own 9.30 mm header pins
200uH @ 100kHz CMC | L1 | t1s_hat:L_CommonMode_TDK_ACT1210_3225 | 1 | fit | Common-mode choke, 2-line, 200 uH @ 100 kHz, EIA 1210 (3.2x2.5 mm), AEC-Q200 - TDK ACT1210L-201-2P-TL00 (AN1718 L1). ALWAYS FITTED. | C131444
220V(1mA) 1.5pF ESD (DNP) [DNP] | MOV1 | t1s_hat:Varistor_TDK_AVRH10_1005 | 1 | DNP | ESD element on bus P, at the connector (AN1718 MOV1) - TDK AVRH10C221KT1R5YA8 chip varistor, 1005 [0402], 1.5 pF. Optional. | C2157827
220V(1mA) 1.5pF ESD (DNP) [DNP] | MOV2 | t1s_hat:Varistor_TDK_AVRH10_1005 | 1 | DNP | ESD element on bus N, at the connector (AN1718 MOV2) - TDK AVRH10C221KT1R5YA8 chip varistor, 1005 [0402], 1.5 pF. Optional. | C2157827
49R9 1% (DNP) [DNP] | R1 | Resistor_SMD:R_1206_3216Metric | 1 | DNP | Bus termination, P leg. 49R9 1% for an END node (AN1718: 1 W; the orderable part is 0.75 W, see ORDERING.md), 1K5 1% for a DROP node. Shipped unstuffed - see README. | C4014562
49R9 1% (DNP) [DNP] | R2 | Resistor_SMD:R_1206_3216Metric | 1 | DNP | Bus termination, N leg. 49R9 1% for an END node (AN1718: 1 W; the orderable part is 0.75 W, see ORDERING.md), 1K5 1% for a DROP node. Shipped unstuffed - see README. | C4014562
100k 1% | R3 | Resistor_SMD:R_0805_2012Metric | 1 | fit | Common-mode termination, centre tap to ground (AN1718 R3) | C149504
10k | R4 | Resistor_SMD:R_0603_1608Metric | 1 | fit | RESET_N pull-up: a floating host GPIO during ESP32 boot must not hold the PHY in reset | C25804
10k | R5 | Resistor_SMD:R_0603_1608Metric | 1 | fit | SPI CS_N pull-up | C25804
10k | R6 | Resistor_SMD:R_0603_1608Metric | 1 | fit | IRQ_N pull-up (open-drain capable interrupt output) | C25804
12k4 1% | R7 | Resistor_SMD:R_0603_1608Metric | 1 | fit | RBIAS. 12.4 kohm 1% over the whole operating temperature range - no substitutions (data sheet). | C22865
LAN8651 | U1 | t1s_hat:TQFN-32-1EP_5x5mm_P0.5mm_EP3.4x3.4mm_ThermalVias_SplitPaste | 1 | fit | Microchip LAN8651 10BASE-T1S MAC-PHY, OPEN Alliance TC6 SPI, 32-VQFN 5x5 (internal 1.8 V core LDO -> single 3.3 V rail) | C22386973
25.000MHz CL12 | Y1 | Crystal:Crystal_SMD_3225-4Pin_3.2x2.5mm | 1 | fit | 25.000 MHz fundamental crystal, CL 12 pF, ESR 50 ohm max, SMD3225-4P - YXC X322525MOB4SI. No series or feedback resistor (data sheet). | C9006

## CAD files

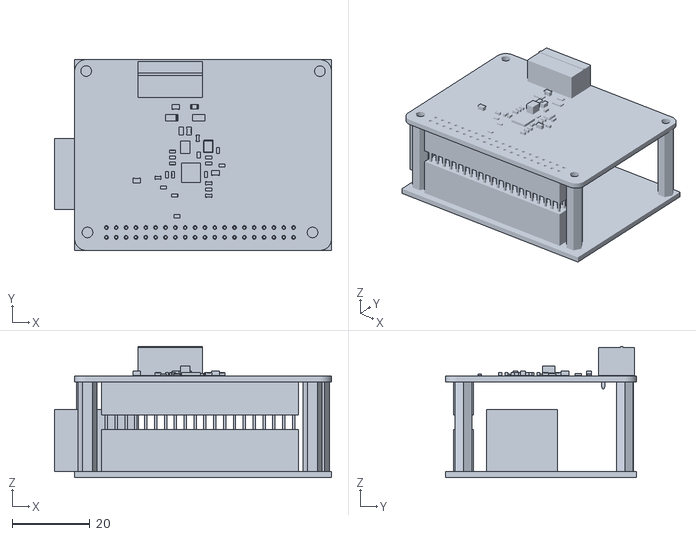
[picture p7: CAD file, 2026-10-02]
mechanical/model/stack.stl
71.4 x 49.2 x 33.8

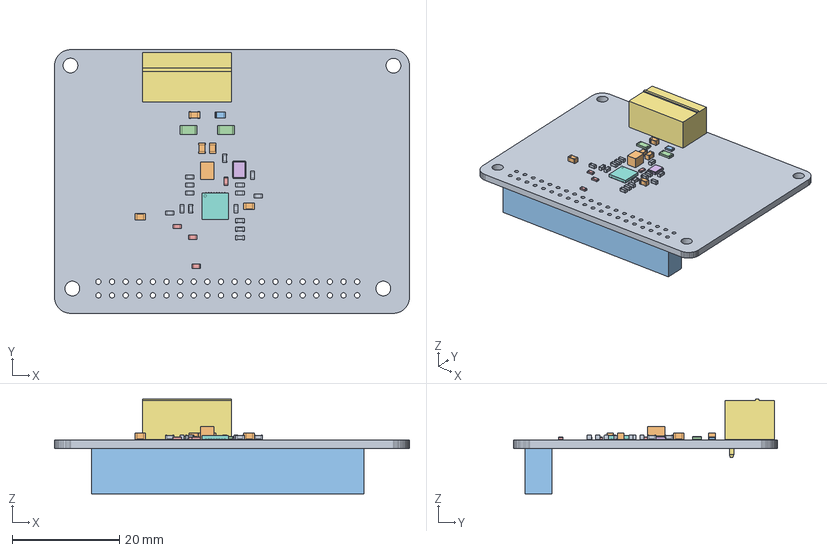
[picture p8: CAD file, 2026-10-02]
mechanical/model/t1s_hat.step
66.2 x 49.2 x 17.7 mm

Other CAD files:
mechanical/model/t1s_hat.stl

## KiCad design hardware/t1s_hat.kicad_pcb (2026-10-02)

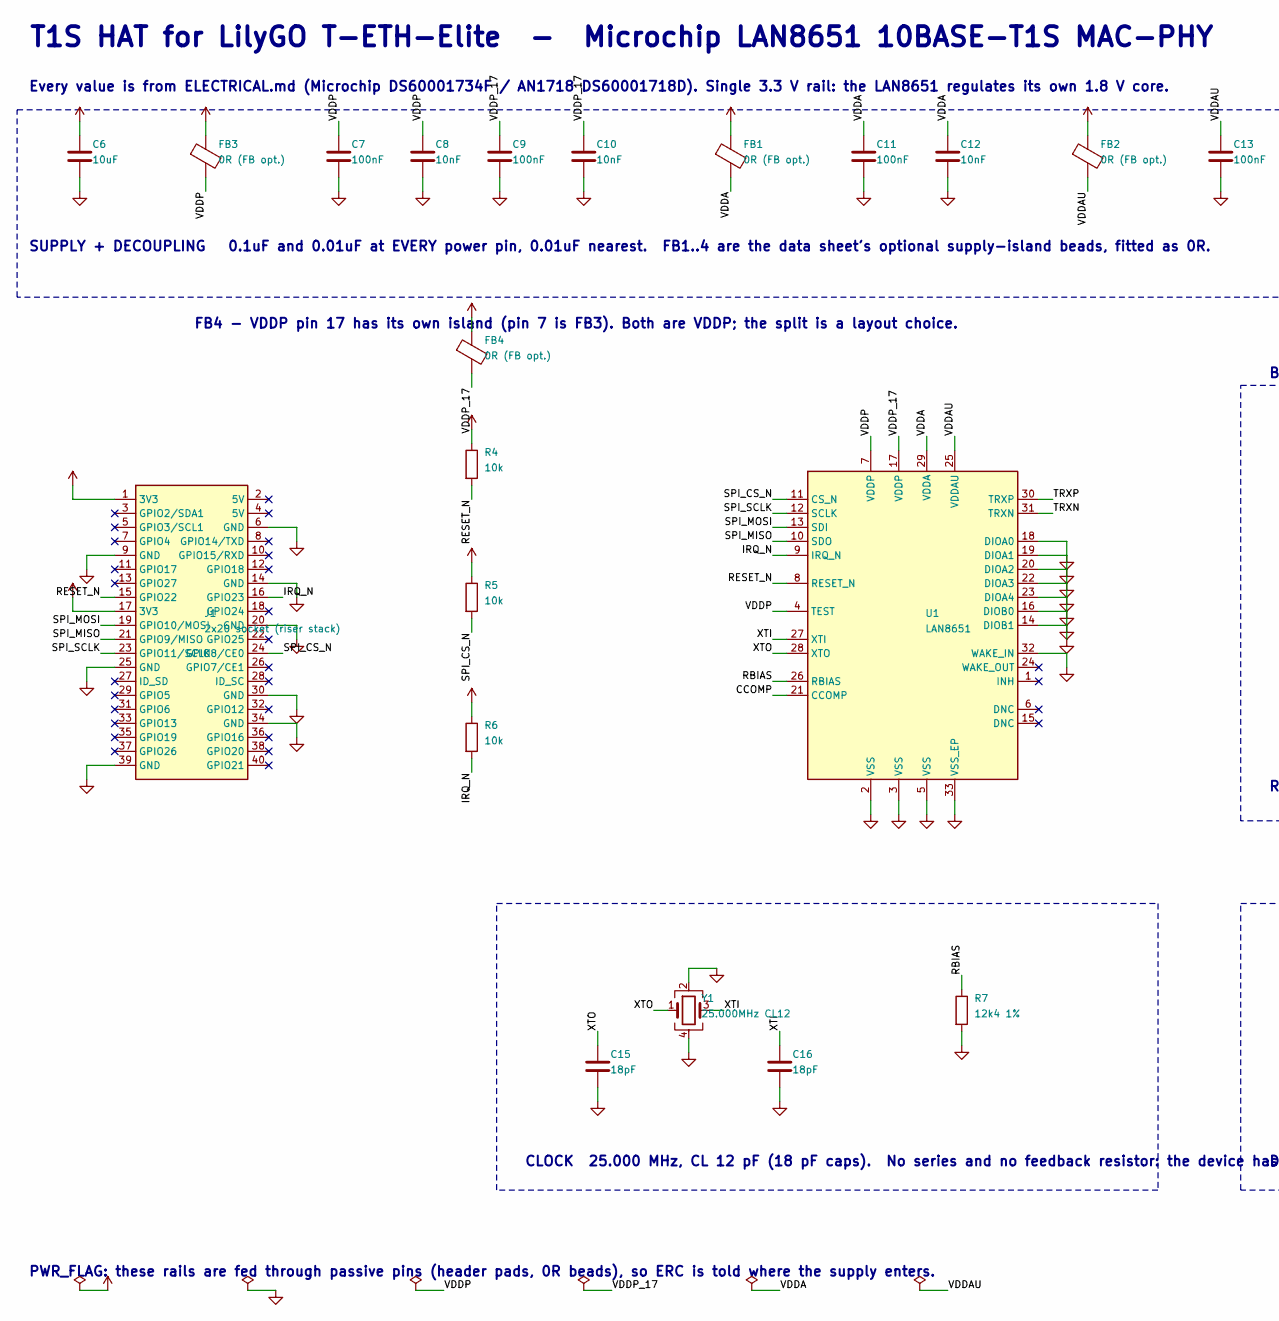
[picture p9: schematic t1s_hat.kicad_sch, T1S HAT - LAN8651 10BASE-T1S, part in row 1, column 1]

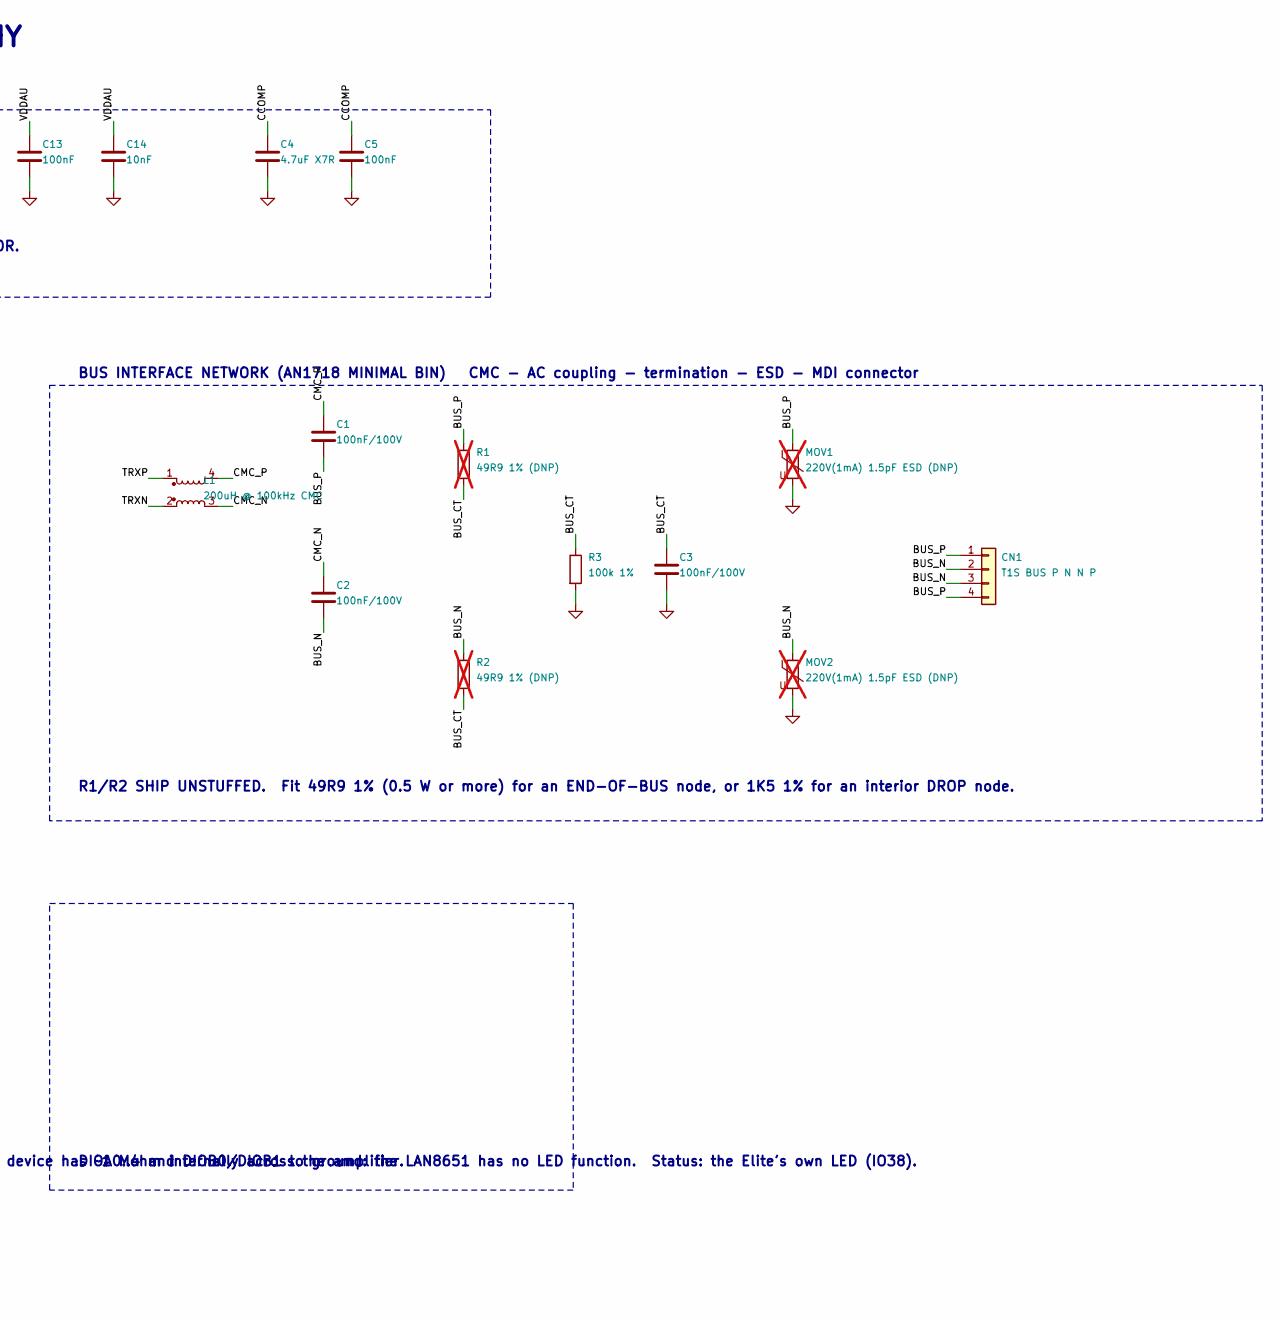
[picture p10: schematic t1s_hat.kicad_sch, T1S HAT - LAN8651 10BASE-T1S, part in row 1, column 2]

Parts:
C1, C2, C3: 100nF/100V; C_0805_2012Metric; LCSC C28233
C4: 4.7uF X7R; C_0805_2012Metric; LCSC C354262
C5, C7, C9, C11, C13: 100nF; C_0603_1608Metric; LCSC C14663
C6: 10uF; C_0805_2012Metric; LCSC C15850
C8, C10, C12, C14: 10nF; C_0603_1608Metric; LCSC C57112
C15, C16: 18pF; C_0603_1608Metric; LCSC C1647
CN1: T1S BUS P N N P; PhoenixContact_MC_1,5_4-G-3.81_1x04_P3.81mm_Horizontal; LCSC C480536
FB1, FB2, FB3, FB4: 0R (FB opt.); L_0603_1608Metric; LCSC C21189
J1: 2x20 socket (riser stack); PinHeader_2x20_P2.54mm_Vertical
L1: 200uH @ 100kHz CMC; L_CommonMode_TDK_ACT1210_3225; LCSC C131444
MOV1, MOV2: 220V(1mA) 1.5pF ESD (DNP); Varistor_TDK_AVRH10_1005; LCSC C2157827; not fitted
R1, R2: 49R9 1% (DNP); R_1206_3216Metric; LCSC C4014562; not fitted
R3: 100k 1%; R_0805_2012Metric; LCSC C149504
R4, R5, R6: 10k; R_0603_1608Metric; LCSC C25804
R7: 12k4 1%; R_0603_1608Metric; LCSC C22865
U1: LAN8651; TQFN-32-1EP_5x5mm_P0.5mm_EP3.4x3.4mm_ThermalVias_SplitPaste; LCSC C22386973
Y1: 25.000MHz CL12; Crystal_SMD_3225-4Pin_3.2x2.5mm; LCSC C9006

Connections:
+3V3: C6.1, FB1.1, FB2.1, FB3.1, FB4.1, J1.1 (3V3), J1.17 (3V3), R4.1, R5.1, R6.1
BUS_CT: C3.1, R1.2, R2.2, R3.1
BUS_N: C2.2, CN1.2, CN1.3, MOV2.1, R2.1
BUS_P: C1.2, CN1.1, CN1.4, MOV1.1, R1.1
CCOMP: C4.1, C5.1, U1.21 (CCOMP)
CMC_N: C2.1, L1.3
CMC_P: C1.1, L1.4
GND: C3.2, C4.2, C5.2, C6.2, C7.2, C8.2, C9.2, C10.2, C11.2, C12.2, C13.2, C14.2, C15.2, C16.2, J1.6 (GND), J1.9 (GND), J1.14 (GND), J1.20 (GND), J1.25 (GND), J1.30 (GND), J1.34 (GND), J1.39 (GND), MOV1.2, MOV2.2, R3.2, R7.2, U1.2 (VSS), U1.3 (VSS), U1.5 (VSS), U1.14 (DIOB1), U1.16 (DIOB0), U1.18 (DIOA0), U1.19 (DIOA1), U1.20 (DIOA2), U1.22 (DIOA3), U1.23 (DIOA4), U1.32 (WAKE_IN), U1.33 (VSS_EP), Y1.2, Y1.4
IRQ_N: J1.16 (GPIO23), R6.2, U1.9 (IRQ_N)
RBIAS: R7.1, U1.26 (RBIAS)
RESET_N: J1.15 (GPIO22), R4.2, U1.8 (RESET_N)
SPI_CS_N: J1.24 (GPIO8/CE0), R5.2, U1.11 (CS_N)
SPI_MISO: J1.21 (GPIO9/MISO), U1.10 (SDO)
SPI_MOSI: J1.19 (GPIO10/MOSI), U1.13 (SDI)
SPI_SCLK: J1.23 (GPIO11/SCLK), U1.12 (SCLK)
TRXN: L1.2, U1.31 (TRXN)
TRXP: L1.1, U1.30 (TRXP)
VDDA: C11.1, C12.1, FB1.2, U1.29 (VDDA)
VDDAU: C13.1, C14.1, FB2.2, U1.25 (VDDAU)
VDDP: C7.1, C8.1, FB3.2, U1.4 (TEST), U1.7 (VDDP)
VDDP_17: C9.1, C10.1, FB4.2, U1.17 (VDDP)
XTI: C16.1, U1.27 (XTI), Y1.3
XTO: C15.1, U1.28 (XTO), Y1.1

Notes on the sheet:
T1S HAT for LilyGO T-ETH-Elite - Microchip LAN8651 10BASE-T1S MAC-PHY
Every value is from ELECTRICAL.md (Microchip DS60001734F / AN1718 DS60001718D). Single 3.3 V rail: the LAN8651 regulates its own 1.8 V core.
SUPPLY + DECOUPLING 0.1uF and 0.01uF at EVERY power pin, 0.01uF nearest. FB1..4 are the data sheet's optional supply-island beads, fitted as 0R.
FB4 - VDDP pin 17 has its own island (pin 7 is FB3). Both are VDDP; the split is a layout choice.
BUS INTERFACE NETWORK (AN1718 MINIMAL BIN) CMC - AC coupling - termination - ESD - MDI connector
R1/R2 SHIP UNSTUFFED. Fit 49R9 1% (0.5 W or more) for an END-OF-BUS node, or 1K5 1% for an interior DROP node.
CLOCK 25.000 MHz, CL 12 pF (18 pF caps). No series and no feedback resistor: the device has ~1 Mohm internally across the amplifier.
DIOA0..4 and DIOB0/DIOB1 to ground: the LAN8651 has no LED function. Status: the Elite's own LED (IO38).
PWR_FLAG: these rails are fed through passive pins (header pads, 0R beads), so ERC is told where the supply enters.

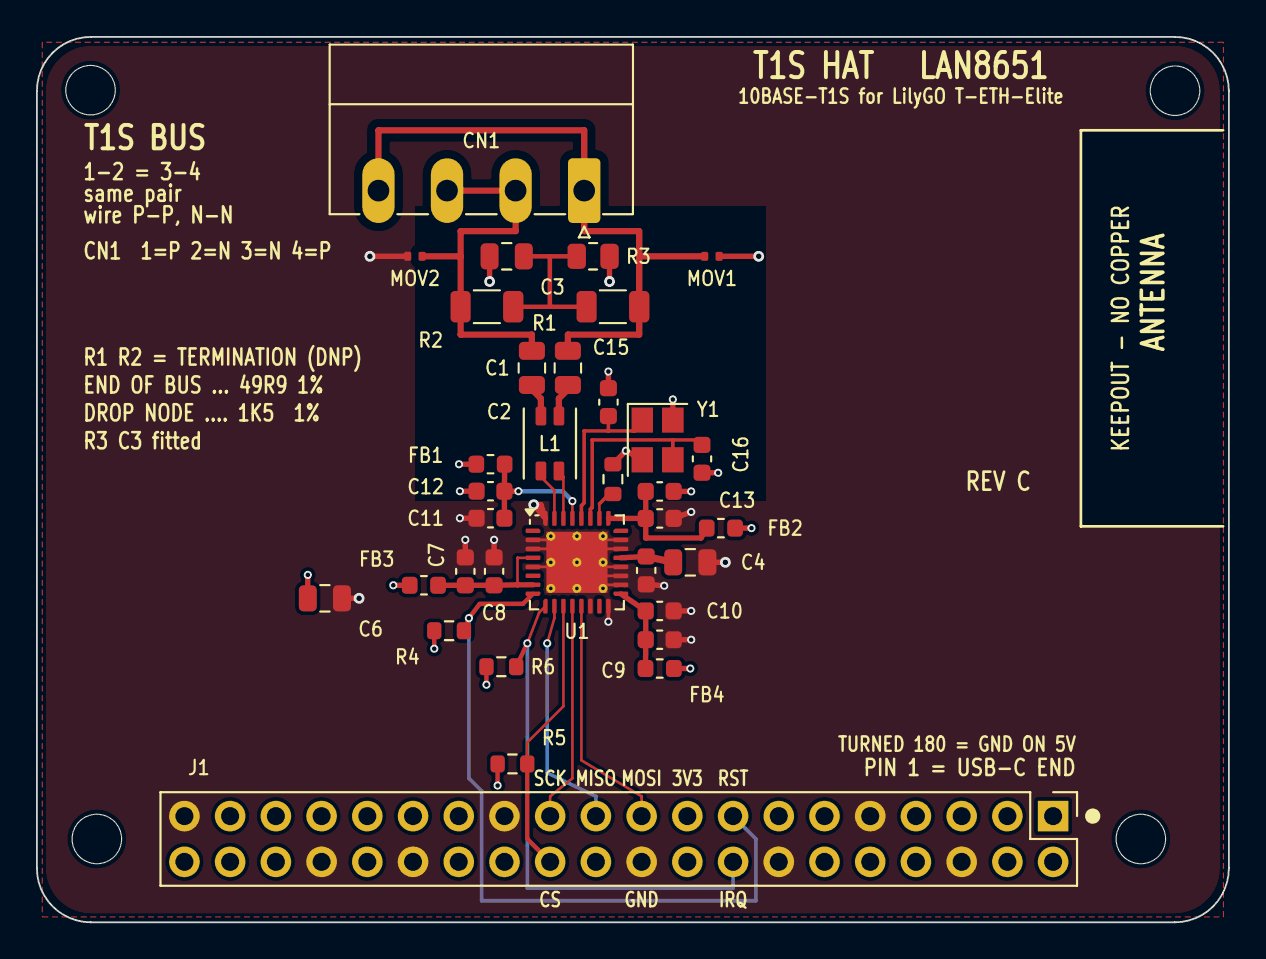
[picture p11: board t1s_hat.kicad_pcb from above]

Board: 4 copper layers, 66.2 x 49.2 mm, 38 parts (0 on the bottom side), 23 nets.

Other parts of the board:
H1, H2, H3, H4: NPTH_2.75mm

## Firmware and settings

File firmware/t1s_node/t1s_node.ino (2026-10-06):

// T1S HAT bring-up and node firmware for the LilyGO T-ETH-Elite.
//
// Brings the HAT's LAN8651 up as an ordinary esp_netif Ethernet interface, so lwIP -- ping,
// UDP, anything else -- runs over 10BASE-T1S unchanged. The MAC-PHY driver is Espressif's
// own (src/lan865x, vendored, see VENDORED.md); this file only does what is specific to this
// board: the pin map (pins.h), the reset line, the IRQ line's pull, PLCA, and a serial
// console for the bench.
//
// Runs on T-ETH-Elite boards (with a third-party LAN8651 HAT; this board is not built yet).
// Every place a first power-up could go wrong prints
// what it saw rather than failing silently -- the chip ID, the SPI error, PLCA as read back.
#include <Arduino.h>
#include <algorithm>
#include <Preferences.h>
#include <esp_eth.h>
#include <esp_event.h>
#include <esp_mac.h>
#include <esp_timer.h>
#include <esp_netif.h>
#include <driver/gpio.h>
#include <driver/spi_master.h>
#include <lwip/sockets.h>
#include <ping/ping_sock.h>
#include "pins.h"
#include "src/lan865x/esp_eth_mac_lan865x.h"
#include "src/lan865x/esp_eth_phy_lan865x.h"
#include "bridge.h"
#include "zenoh_t1s.h"
#include "net_console.h"

// w5500_spi.h (shared with the W5500 bench firmware) declares this extern; one definition per image.
W5500Spi *gW5500Spi = nullptr;

// The LAN8651 is rated to 25 MHz SCLK (DS60001734F, Table 9-9), and every frame crosses this link,
// so the clock IS the throughput. The ESP32-S3 divides 80 MHz by an integer and rounds to the
// nearest divider, so asking 25 used to run 80/3 = 26.67 MHz -- out of spec; bring-up now lowers
// the request until the clock that actually runs is <= 25, which on this chip means 20 MHz (80/4).
// Measured with a LAN8651 HAT: 11.43 MHz gives 6.0/6.3 Mbit/s, 20 MHz 8.0/8.4, and the out-of-spec
// 26.67 MHz 9.0/9.5 (to/from the node). 25 stays the default request, and bring-up steps down
// (25 -> 20 -> 12 -> 4) by itself if the driver cannot install at a clock -- the driver checks
// the parity of every control reply, so a clock the wiring cannot carry fails install rather
// than corrupting silently. `spi <mhz>` + `save` sets the starting clock.
constexpr uint8_t kDefaultSpiMhz = 25;
constexpr int kSpiMaxHz = 25 * 1000 * 1000;   // LAN8651 fSCK max

// PLCA node ID 255 means "PLCA off, plain CSMA/CD". 0 is the coordinator, which sends the
// BEACON and whose node count sets the cycle; every bus with PLCA needs exactly one.
constexpr uint8_t kPlcaOff = 255;

// node:   this board is a T1S endpoint with its own IP (lwIP on the LAN8651)
// bridge: W5500 100BASE-TX <-> LAN8651 10BASE-T1S learning bridge, no IP (bridge.h)
// sniff:  receive-only bus analyser -- every T1S frame copied out of the W5500, PLCA off, no
//         IP, never transmits on T1S (the converter's "ID >= 1, count 0" mode, on this board)
// tx:     no LAN8651 at all -- the Elite's W5500 as an ordinary IP endpoint (echo, sink,
//         blast, ping). The second board of a two-ESP bench, standing in for the PC on the
//         converter's 100BASE-TX port.
enum Mode : uint8_t { kModeNode = 0, kModeBridge = 1, kModeSniff = 2, kModeTx = 3 };
static const char *modeName(uint8_t m) {
  return m == kModeBridge ? "bridge" : m == kModeSniff ? "sniff" : m == kModeTx ? "tx" : "node";
}

struct Config {
  uint8_t mode = kModeNode;
  uint8_t plcaId = kPlcaOff;
  uint8_t plcaCount = 8;
  uint8_t spiMhz = kDefaultSpiMhz;
  uint32_t ip = 0;     // 0 = derive from the node ID, see defaultIp()
  uint32_t mask = 0;   // 0 = 255.255.255.0
  uint8_t lan = 1;     // mode node: also bring up the board's own RJ45 (W5500)
  uint32_t lanIp = 0;  // 0 = DHCP
  uint32_t lanMask = 0;
};

static Config gCfg;
static Preferences gPrefs;
static esp_eth_handle_t gEth = nullptr;
static esp_eth_mac_t *gMac = nullptr;
static esp_netif_t *gNetif = nullptr;
static esp_netif_t *gLan = nullptr;   // mode node: the W5500 next to T1S
static volatile bool gLanUp = false;
static volatile bool gLinkUp = false;
static uint8_t gSpiMhzRunning = 0;   // the clock bring-up actually settled on
static float gSpiActualMhz = 0;      // what the SPI peripheral really runs: 80 MHz / an integer divider
static volatile uint32_t gEchoCount = 0;
// port 9 (discard) sink: what a peer's `blast` actually delivered here
static volatile uint32_t gSinkPackets = 0;
static volatile uint64_t gSinkBytes = 0;
static volatile uint32_t gSinkT0 = 0, gSinkLast = 0;
static uint32_t gIdentifyUntil = 0;  // `identify`: LED strobes until then
static uint32_t gRebootAtMs = 0;   // a remote `reboot`: delayed so its ack can leave first

// 192.168.50.(10 + id), or .9 with PLCA off. A separate /24 from the W5500 bench
// (192.168.1.x) so the two interfaces can be up together later without a routing question.
static uint32_t defaultIp() {
  // tx mode sits on the bench LAN next to the HAT (192.168.100.65 there), as the PC did
  if (gCfg.mode == kModeTx) return (uint32_t)IPAddress(192, 168, 100, 66);
  const uint8_t last = gCfg.plcaId == kPlcaOff ? 9 : 10 + gCfg.plcaId;
  return (uint32_t)IPAddress(192, 168, 50, last);
}

static void loadConfig() {
  gPrefs.begin("t1s", true);
  gCfg.mode = gPrefs.getUChar("mode", gCfg.mode);
  gCfg.plcaId = gPrefs.getUChar("id", gCfg.plcaId);
  gCfg.plcaCount = gPrefs.getUChar("cnt", gCfg.plcaCount);
  gCfg.spiMhz = gPrefs.getUChar("mhz", gCfg.spiMhz);
  gCfg.ip = gPrefs.getULong("ip", 0);
  gCfg.mask = gPrefs.getULong("mask", 0);
  gCfg.lan = gPrefs.getUChar("lan", gCfg.lan);
  gCfg.lanIp = gPrefs.getULong("lanip", 0);
  gCfg.lanMask = gPrefs.getULong("lanmask", 0);
  gPrefs.end();
}

static void saveConfig() {
  gPrefs.begin("t1s", false);
  gPrefs.putUChar("mode", gCfg.mode);
  gPrefs.putUChar("id", gCfg.plcaId);
  gPrefs.putUChar("cnt", gCfg.plcaCount);
  gPrefs.putUChar("mhz", gCfg.spiMhz);
  gPrefs.putULong("ip", gCfg.ip);
  gPrefs.putULong("mask", gCfg.mask);
  gPrefs.putUChar("lan", gCfg.lan);
  gPrefs.putULong("lanip", gCfg.lanIp);
  gPrefs.putULong("lanmask", gCfg.lanMask);
  gPrefs.end();
}

// Two Ethernet drivers can run at once (T1S + the board's RJ45), so the event says which one.
static void onEthEvent(void *, esp_event_base_t, int32_t id, void *data) {
  const esp_eth_handle_t h = data ? *(esp_eth_handle_t *)data : nullptr;
  const bool lan = gCfg.mode == kModeNode && h && h == bridge::gNodeTx;
  const bool up = id == ETHERNET_EVENT_CONNECTED;
  if (id != ETHERNET_EVENT_CONNECTED && id != ETHERNET_EVENT_DISCONNECTED) return;
  if (lan) gLanUp = up;
  else gLinkUp = up;
  Con.printf("%s: link %s\n", lan ? "lan" : gCfg.mode == kModeTx ? "w5500" : "t1s", up ? "up" : "down");
}

// ---------------------------------------------------------------- PLCA

// A sniffer keeps the saved PLCA settings but never runs them: it must not take a slot.
static bool plcaWanted() { return gCfg.plcaId != kPlcaOff && gCfg.mode != kModeSniff; }

static esp_err_t applyPlca() {
  bool enable = plcaWanted();
  esp_err_t err = ESP_OK;
  if (enable) {
    uint8_t id = gCfg.plcaId, cnt = gCfg.plcaCount;
    if ((err = esp_eth_ioctl(gEth, (esp_eth_io_cmd_t)LAN86XX_ETH_CMD_S_PLCA_ID, &id)) != ESP_OK) return err;
    if ((err = esp_eth_ioctl(gEth, (esp_eth_io_cmd_t)LAN86XX_ETH_CMD_S_PLCA_NCNT, &cnt)) != ESP_OK) return err;
  }
  return esp_eth_ioctl(gEth, (esp_eth_io_cmd_t)LAN86XX_ETH_CMD_S_EN_PLCA, &enable);
}

// What the PHY says, not what was asked for -- the only version worth printing.
static void printPlca() {
  bool en = false;
  uint8_t id = 0, cnt = 0;
  esp_eth_ioctl(gEth, (esp_eth_io_cmd_t)LAN86XX_ETH_CMD_G_EN_PLCA, &en);
  esp_eth_ioctl(gEth, (esp_eth_io_cmd_t)LAN86XX_ETH_CMD_G_PLCA_ID, &id);
  esp_eth_ioctl(gEth, (esp_eth_io_cmd_t)LAN86XX_ETH_CMD_G_PLCA_NCNT, &cnt);
  if (en) Con.printf("plca: on, id %u of %u%s\n", id, cnt, id == 0 ? " (coordinator)" : "");
  else Con.println("plca: off (CSMA/CD)");
}

// ---------------------------------------------------------------- bring-up

// Read the LAN8651's DEVID (MMS 10, 0x94) with one raw OPEN Alliance TC6 control read, before
// any driver exists, to find out which way round MOSI/MISO really are. LilyGo's own schematic
// and example code agree on MOSI=IO11 / MISO=IO9, but their printed pinout image had IO9/IO11
// swapped (LilyGO-T-ETH-Series issue #100) -- so the firmware checks instead of trusting either.
// Frame: 4-byte header + 4 data + 4 dummy out; 4 dummy + echoed header + register back.
static uint32_t tc6RawReadDevid(int mosi, int miso) {
  spi_bus_config_t bus = {};
  bus.mosi_io_num = mosi;
  bus.miso_io_num = miso;
  bus.sclk_io_num = kPinT1sSclk;
  bus.quadwp_io_num = -1;
  bus.quadhd_io_num = -1;
  if (spi_bus_initialize(SPI3_HOST, &bus, SPI_DMA_DISABLED) != ESP_OK) return 0;
  spi_device_interface_config_t dev = {};
  dev.mode = 0;
  dev.clock_speed_hz = 4 * 1000 * 1000;  // slow on purpose: this is a wiring test
  dev.spics_io_num = kPinT1sCs;
  dev.queue_size = 1;
  spi_device_handle_t h = nullptr;
  uint32_t devid = 0;
  if (spi_bus_add_device(SPI3_HOST, &dev, &h) == ESP_OK) {
    uint32_t hdr = (0u << 31) | (0u << 30) | (0u << 29) | (1u << 28) | (10u << 24) | (0x94u << 8) | (0u << 1);
    uint32_t ones = __builtin_popcount(hdr >> 1);
    if (!(ones & 1)) hdr |= 1;  // odd parity over bits 31..0
    uint8_t tx[12] = {(uint8_t)(hdr >> 24), (uint8_t)(hdr >> 16), (uint8_t)(hdr >> 8), (uint8_t)hdr};
    uint8_t rx[12] = {};
    spi_transaction_t t = {};
    t.length = sizeof(tx) * 8;
    t.tx_buffer = tx;
    t.rx_buffer = rx;
    if (spi_device_polling_transmit(h, &t) == ESP_OK)
      devid = ((uint32_t)rx[8] << 24) | ((uint32_t)rx[9] << 16) | ((uint32_t)rx[10] << 8) | rx[11];
    spi_bus_remove_device(h);
  }
  spi_bus_free(SPI3_HOST);
  return devid;
}

static bool isLan865x(uint32_t devid) {
  const uint32_t model = (devid >> 4) & 0xFFFF;
  return model == 0x8650 || model == 0x8651;
}

static bool t1sStart(bool withNetif) {
  // Deselect the TF card: it shares MOSI/MISO/SCLK with the HAT.
  pinMode(kPinSdCs, OUTPUT);
  digitalWrite(kPinSdCs, HIGH);

  // Hardware reset. The HAT pulls RESET_N up (R4), so this is belt and braces: whatever the
  // GPIO did during the ESP32's own boot, the chip starts from a known state. The driver
  // then does its own software reset on top.
  pinMode(kPinT1sReset, OUTPUT);
  digitalWrite(kPinT1sReset, LOW);
  delay(2);
  digitalWrite(kPinT1sReset, HIGH);
  delay(10);

  esp_netif_init();
  esp_event_loop_create_default();
  gpio_install_isr_service(0);  // the LAN865x driver is interrupt-driven

  int mosi = kPinT1sMosi, miso = kPinT1sMiso;
  uint32_t probed = tc6RawReadDevid(mosi, miso);
  if (!isLan865x(probed)) {
    const uint32_t swapped = tc6RawReadDevid(miso, mosi);
    Con.printf("t1s: probe MOSI=IO%d MISO=IO%d -> 0x%08lx, swapped -> 0x%08lx\n", mosi, miso,
                  (unsigned long)probed, (unsigned long)swapped);
    if (isLan865x(swapped)) {
      mosi = kPinT1sMiso;
      miso = kPinT1sMosi;
      Con.println("t1s: MOSI/MISO are the other way round on this board -- using the swapped mapping");
    }
  } else {
    Con.printf("t1s: probe OK, DEVID 0x%08lx (MOSI=IO%d MISO=IO%d)\n", (unsigned long)probed, mosi, miso);
  }

  spi_bus_config_t bus = {};
  bus.mosi_io_num = mosi;
  bus.miso_io_num = miso;
  bus.sclk_io_num = kPinT1sSclk;
  bus.quadwp_io_num = -1;
  bus.quadhd_io_num = -1;
  // SPI3, not SPI2: SPI2 is what the W5500 firmware already uses, so the
  // two can later run in one image as a T1S <-> 100BASE-TX bridge.
  esp_err_t err = spi_bus_initialize(SPI3_HOST, &bus, SPI_DMA_CH_AUTO);
  Con.printf("t1s: spi bus: %s\n", esp_err_to_name(err));
  if (err != ESP_OK) return false;
  // Softer edges instead of series damping resistors: ~20 mm of riser stack between the ESP32
  // and the HAT, and the ESP32-S3's default drive (~20 mA) rings on it for no benefit at
  // <= 25 MHz. CAP_1 is ~10 mA. Raise it back with `spi` tests if edges ever look too slow.
  for (int pin : {kPinT1sSclk, mosi, kPinT1sCs}) gpio_set_drive_capability((gpio_num_t)pin, GPIO_DRIVE_CAP_1);

  // Install at the configured clock; on failure free the driver and step down.
  static spi_device_interface_config_t dev = {};   // static: the driver keeps a pointer
  const uint8_t steps[] = {gCfg.spiMhz, 20, 12, 4};
  eth_mac_config_t macCfg = ETH_MAC_DEFAULT_CONFIG();
  eth_phy_config_t phyCfg = ETH_PHY_DEFAULT_CONFIG();
  phyCfg.reset_gpio_num = -1;  // done above
  for (uint8_t mhz : steps) {
    if (mhz > gCfg.spiMhz) continue;           // only ever step down from the configured clock
    // Never above the LAN8651's 25 MHz: walk the request down until the divider it lands on is in spec.
    int hz = mhz * 1000 * 1000;
#pragma GCC diagnostic push
#pragma GCC diagnostic ignored "-Wdeprecated-declarations"
    while (hz > 1000000 && spi_get_actual_clock(80 * 1000 * 1000, hz, 128) > kSpiMaxHz) hz -= 500000;
    hz = spi_get_actual_clock(80 * 1000 * 1000, hz, 128);
#pragma GCC diagnostic pop
    dev = {};
    dev.mode = 0;
    dev.clock_speed_hz = hz;
    dev.spics_io_num = kPinT1sCs;
    dev.queue_size = 20;
    // Field by field rather than ETH_LAN865X_DEFAULT_CONFIG: that macro lists its designators
    // out of declaration order, which C accepts and C++ (this file) rejects.
    eth_lan865x_config_t lanCfg = {};
    lanCfg.spi_host_id = SPI3_HOST;
    lanCfg.spi_devcfg = &dev;
    lanCfg.int_gpio_num = kPinT1sIrq;
    lanCfg.poll_period_ms = 0;  // interrupt-driven; the driver rejects both or neither
    lanCfg.custom_spi_driver = ETH_DEFAULT_SPI;
    gMac = esp_eth_mac_new_lan865x(&lanCfg, &macCfg);
    esp_eth_phy_t *phy = esp_eth_phy_new_lan865x(&phyCfg);
    if (!gMac || !phy) { Con.println("t1s: driver alloc failed"); return false; }
    esp_eth_config_t ethCfg = ETH_DEFAULT_CONFIG(gMac, phy);
    err = esp_eth_driver_install(&ethCfg, &gEth);
    // This is the line that says whether the board works at all: install runs the chip reset,
    // reads DEVID and refuses anything but 0x8650/0x8651. ESP_ERR_TIMEOUT or ESP_ERR_INVALID_CRC
    // means SPI did not reach the chip at this clock: check the riser and CS on IO0.
    Con.printf("t1s: driver install at %u MHz: %s\n", mhz, esp_err_to_name(err));
    if (err == ESP_OK) {
      gSpiMhzRunning = mhz;
      // 25 and 22 asked both run 20 (80/4), 18 and 15 give 16, 12 gives 11.43
      gSpiActualMhz = hz / 1e6f;
      Con.printf("t1s: SPI %u MHz asked, %.2f MHz actual\n", mhz, gSpiActualMhz);
      break;
    }
    gMac->del(gMac);
    phy->del(phy);
    gMac = nullptr;
    gEth = nullptr;
    gpio_isr_handler_remove((gpio_num_t)kPinT1sIrq);
  }
  if (err != ESP_OK) return false;
  uint32_t devid = 0;
  if (esp_eth_mac_lan865x_read_reg(gMac, 10, 0x94, &devid) == ESP_OK)
    Con.printf("t1s: chip LAN%04lx rev %lu\n", (unsigned long)((devid >> 4) & 0xFFFF),
                  (unsigned long)(devid & 0xF));

  // The driver turns the ESP32's internal pull-DOWN on for the IRQ pin (it assumes nothing
  // else is there). This board has a 10k pull-up (R6) on IRQ_N, and ~45k internal down against
  // 10k up parks the idle level near 2.7 V -- above VIH, but for no reason. Undo it.
  gpio_pulldown_dis((gpio_num_t)kPinT1sIrq);
  gpio_pullup_en((gpio_num_t)kPinT1sIrq);

  // The LAN8651 has no MAC address of its own; take the ESP32's Ethernet efuse address so
  // two nodes cannot collide.
  uint8_t mac[6];
  esp_read_mac(mac, ESP_MAC_ETH);
  esp_eth_ioctl(gEth, ETH_CMD_S_MAC_ADDR, mac);
  Con.printf("t1s: mac %02x:%02x:%02x:%02x:%02x:%02x\n", mac[0], mac[1], mac[2], mac[3], mac[4], mac[5]);

  err = applyPlca();
  Con.printf("t1s: plca config: %s\n", esp_err_to_name(err));
  printPlca();

  if (!withNetif) {  // bridge mode: bridge.h takes the input path over, nothing for lwIP
    err = esp_eth_start(gEth);
    Con.printf("t1s: start (no IP, bridge port): %s\n", esp_err_to_name(err));
    return err == ESP_OK;
  }
  esp_netif_config_t nifCfg = ESP_NETIF_DEFAULT_ETH();
  gNetif = esp_netif_new(&nifCfg);
  esp_netif_dhcpc_stop(gNetif);  // closed bench bus, static addressing
  esp_netif_ip_info_t ip = {};
  ip.ip.addr = gCfg.ip ? gCfg.ip : defaultIp();
  ip.netmask.addr = gCfg.mask ? gCfg.mask : (uint32_t)IPAddress(255, 255, 255, 0);
  esp_netif_set_ip_info(gNetif, &ip);
  esp_netif_attach(gNetif, esp_eth_new_netif_glue(gEth));
  bridge::countInput(gEth, gNetif);
  esp_event_handler_register(ETH_EVENT, ESP_EVENT_ANY_ID, onEthEvent, nullptr);

  err = esp_eth_start(gEth);
  Con.printf("t1s: start: %s, ip " IPSTR "\n", esp_err_to_name(err), IP2STR(&ip.ip));
  return err == ESP_OK;
}

// ---------------------------------------------------------------- UDP echo (port 7)

// The other end of every test below: anything sent to port 7 comes straight back, so a PC
// or another node can measure round-trip time over the bus with nothing on this side but
// this task.
static void echoTask(void *) {
  int s = socket(AF_INET, SOCK_DGRAM, 0);
  sockaddr_in a = {};
  a.sin_family = AF_INET;
  a.sin_port = htons(7);
  bind(s, (sockaddr *)&a, sizeof(a));
  static uint8_t buf[1536];
  for (;;) {
    sockaddr_in from;
    socklen_t fl = sizeof(from);
    int n = recvfrom(s, buf, sizeof(buf), 0, (sockaddr *)&from, &fl);
    if (n > 0) { sendto(s, buf, n, 0, (sockaddr *)&from, fl); gEchoCount = gEchoCount + 1; }
  }
}

// The receiving half of `blast`: count what arrives on port 9 and drop it. `sink` on this
// node then says what the far side's offered load turned into after the bus.
// Sink statistics, written by the sink task only. A `sink reset` is a request the task carries
// out before its next packet, so the console never races it.
struct SinkSeq {
  uint32_t minSeq = UINT32_MAX, maxSeq = 0, last = 0, reordered = 0, dup = 0;
  int64_t tPrev = 0, gapMax = 0, t0us = 0, t1us = 0;
  uint64_t bytesAfterFirst = 0;  // the rate is (everything after the first datagram) / (first..last)
  // inter-arrival gaps: [0..99] 20 us bins up to 2 ms, [100..147] 1 ms bins up to 50 ms, [148] beyond
  uint32_t gapHist[149] = {};
  static int gapBin(int64_t g) { return g < 2000 ? (int)(g / 20) : g < 50000 ? 100 + (int)((g - 2000) / 1000) : 148; }
  static uint32_t binMid(int i) { return i < 100 ? i * 20 + 10 : i < 148 ? 2000 + (i - 100) * 1000 + 500 : 50000; }
  // a member, not a free function: Arduino's prototype pass would declare it before this struct
  uint32_t gapPct(uint32_t total, float p) const {
    uint32_t acc = 0, want = (uint32_t)(total * p);
    for (int i = 0; i < 149; i++) {
      acc += gapHist[i];
      if (acc > want) return binMid(i);
    }
    return 50000;
  }
};
static SinkSeq gSeq;
static volatile bool gSinkResetReq = false;
static uint32_t gSinkSeen[64];  // bitmap of the last 2048 seqs, for duplicates
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
void loop() {
  static char line[128];
  static size_t len = 0;
  // USB serial and the WiFi console feed the same line editor
  for (;;) {
    int ci = Serial.available() ? Serial.read() : netConsoleRead();
    if (ci < 0) break;
    const char c = (char)ci;
    if (c == '\r') continue;
    if (c == '\n') { line[len] = 0; handleLine(line); len = 0; }
    else if (len < sizeof(line) - 1) line[len++] = c;
  }
  char remote[100];
  if (zenohT1sTakeConfig(remote, sizeof(remote))) runRemoteConfig(remote);
  if (gRebootAtMs && (int32_t)(millis() - gRebootAtMs) >= 0) ESP.restart();
  // No background register polling beyond PLCA_STS: an automatic read of the guessed GEM
  // statistics block every 5 s stopped this LAN8651 from transmitting (2026-10-02, on hardware).
  // Board LED (the Elite's own, IO38) shows T1S state -- the LAN8651 has no LED function
  // of its own (its DIOA pins are event capture/generator only):
  //   PLCA on:  solid = beacons seen (PLCA_STS.PST), fast blink = no beacons
  //   PLCA off: solid = link up
  //   no link:  slow blink
  static uint32_t tPst = 0;
  static bool pst = false;
  const bool plcaOn = plcaWanted();
  if (plcaOn && gMac && millis() - tPst > 250) {
    tPst = millis();
    uint32_t v = 0;
    if (esp_eth_mac_lan865x_read_reg(gMac, 4, 0xCA03, &v) == ESP_OK) pst = v & 0x8000;
  }
  bool on;
  if (gIdentifyUntil && (int32_t)(millis() - gIdentifyUntil) < 0) on = (millis() / 60) & 1;  // ~8 Hz strobe
  // one-shots from `evt` over everything else: horn = 12 Hz strobe 0.6 s, flash = two long blinks
  else if ((int32_t)(millis() - gHornUntil) < 0) on = (millis() / 40) & 1;
  else if ((int32_t)(millis() - gFlashUntil) < 0) on = ((gFlashUntil - millis()) / 125) & 1;
  // turn signal from `evt`: left = 1.5 Hz, right = 1.5 Hz with a double flash, hazard = 3 Hz
  else if (gIndicator == 1) on = (millis() % 667) < 333;
  else if (gIndicator == 2) on = (millis() % 667) < 90 || ((millis() % 667) > 180 && (millis() % 667) < 270);
  else if (gIndicator == 3) on = (millis() % 333) < 166;
  else if (!gLinkUp) on = (millis() / 500) & 1;
  else if (plcaOn) on = pst || ((millis() / 125) & 1);
  else on = true;
  digitalWrite(kPinBoardLed, on ? HIGH : LOW);
  delay(1);   // was 5: `w` lines from the PC's wheel feed come at ~1 kHz and their age is measured
}

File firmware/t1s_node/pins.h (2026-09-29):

// Where the T1S HAT's six host signals land on the T-ETH-Elite's ESP32-S3.
//
// Read off LilyGo's own schematic (schematic/T-ETH-ELite.pdf, sheet 2, J1), not the Pi
// pinout: the HAT was laid out to TSN Lab's Raspberry Pi device-tree overlay, so each
// signal sits on the header pin a Pi would use, and this table is what the Elite has
// wired to those pins.
//
//   HAT signal      header pin   Pi name          Elite
//   SDI  (MOSI)     19           GPIO10 MOSI      IO11  SPI_MOSI  (shared with the TF card)
//   SDO  (MISO)     21           GPIO9  MISO      IO9   SPI_MISO  (shared with the TF card)
//   SCLK            23           GPIO11 SCLK      IO10  SPI_SCLK  (shared with the TF card)
//   CS_N            24           GPIO8  CE0       IO0   BOOT      <-- strapping pin, see below
//   IRQ_N           16           GPIO23           IO39
//   RESET_N         15           GPIO22           IO42
//
// CS_N on IO0. That is where the Pi convention puts CE0, and on the Elite pin 24 is the
// BOOT line. It works: the strap wants IO0 high at reset, the Elite pulls it up (R1 10k)
// and so does the HAT (R5 10k), and the LAN8651's CS_N is an input, so nothing on the HAT
// can pull it low. Two consequences that are real, though:
//   - pressing the Elite's BOOT button while running asserts CS_N and corrupts whatever
//     transaction is on the wire. The driver sees a parity error and retries; do not
//     press it on a live bus.
//   - holding BOOT at power-up still enters the ROM downloader as usual. Flashing is
//     unaffected.
//
// The three bus pins are the Elite's general SPI, which also runs the TF card slot
// (CS IO12). The card is deselected at boot (kPinSdCs driven high) so it cannot answer
// on the LAN8651's transactions; using the card at the same time would need a shared
// spi bus handle, which this firmware does not do.
//
// The Elite's own W5500 is on a separate bus (IO47/21/48/45) and is untouched here.
#pragma once

constexpr int kPinT1sMosi = 11;
constexpr int kPinT1sMiso = 9;
constexpr int kPinT1sSclk = 10;
constexpr int kPinT1sCs = 0;
constexpr int kPinT1sIrq = 39;
constexpr int kPinT1sReset = 42;

constexpr int kPinSdCs = 12;    // TF card chip select on the same bus -- held high
constexpr int kPinBoardLed = 38; // Elite's green LED (header pin 18)

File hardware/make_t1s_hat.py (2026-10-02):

#!/usr/bin/env python3
"""
Generate the T1S HAT: symbol library, schematic, PCB, and all fab outputs.

Run:  python3 make_t1s_hat.py      (KiCad 7 pcbnew Python bindings required)

Sources of truth, in this order:
  ../mechanical/GEOMETRY.md  mechanical   (outline, holes, 2x20 grid) -- inherited
  ELECTRICAL.md        electrical   (every part, value and pin rule)

Nothing in either file is re-derived here.  Deviations from them that were
directed by the project owner after those files were written are marked
"DIRECTED:" in the comments and are listed in README.md.

COORDINATE FRAME -- read before touching a number
-------------------------------------------------
GEOMETRY.md's frame ("G frame"): T-ETH-Elite top view, origin at the Elite's
PCB bottom-left corner, +x right, +y UP.  KiCad's PCB frame has +y DOWN.
The single conversion is kx()/ky()/V(); the G origin sits at KiCad (100,100).
Same convention as the T-ETH-Elite adapter board generator, from which the mechanical code here
is reused.
"""

import csv
import json
import math
import os
import re
import subprocess
import sys
import uuid as _uuid
import zipfile

import pcbnew

HERE = os.path.dirname(os.path.abspath(__file__))
NAME = "t1s_hat"
PCB_PATH = os.path.join(HERE, NAME + ".kicad_pcb")
SCH_PATH = os.path.join(HERE, NAME + ".kicad_sch")
PRO_PATH = os.path.join(HERE, NAME + ".kicad_pro")
SYMDIR = os.path.join(HERE, "sym")
SYMLIB = os.path.join(SYMDIR, "t1s_hat.kicad_sym")
FPDIR = os.path.join(HERE, "fp", "t1s_hat.pretty")

KSYM = "/usr/share/kicad/symbols/"
KFP = "/usr/share/kicad/footprints/"


def fp_dir(lib):
    """Directory holding footprint library `lib`.  Project-local parts live in
    fp/t1s_hat.pretty; everything else comes from the KiCad install."""
    return FPDIR if lib == "t1s_hat" else KFP + lib + ".pretty"

# ---------------------------------------------------------------- frame ----
ORIGIN_X = 100.0
ORIGIN_Y = 100.0


def kx(gx):
    return ORIGIN_X + gx


def ky(gy):
    return ORIGIN_Y - gy


def V(gx, gy):
    return pcbnew.VECTOR2I(pcbnew.FromMM(kx(gx)), pcbnew.FromMM(ky(gy)))


def MM(v):
    return pcbnew.FromMM(v)


def SZ(w, h):
    return pcbnew.VECTOR2I(pcbnew.FromMM(w), pcbnew.FromMM(h))


def gof(pt):
    """KiCad VECTOR2I -> G-frame (x, y) in mm."""
    return (pcbnew.ToMM(pt.x) - ORIGIN_X, ORIGIN_Y - pcbnew.ToMM(pt.y))


# ------------------------------------------------- GEOMETRY.md mechanical --
# DIRECTED: the RJ45 notch is dropped; this board is lifted clear of the jack
# by a taller riser instead, so the outline is the plain rectangle.  Every
# other mechanical number below is GEOMETRY.md's, unchanged.
BOARD_W = 66.22
BOARD_H = 49.19
CORNER_R = 3.0
BOARD_T = 1.6

HOLE_D = 2.75
HOLES = [
    ("H1", 3.33, 4.63, "T-ETH-Elite bottom-left"),
    ("H2", 61.33, 4.63, "T-ETH-Elite bottom-right"),
    ("H3", 2.98, 46.23, "T-ETH-Elite top-left"),
    ("H4", 63.23, 46.20, "T-ETH-Elite top-right"),
]

# Pin NUMBERING on the grid, corrected 2026-09-28: pin 1 is at the USB-C end
# (high x) and the odd pins are on the INNER row (y 5.900), the even pins
# (5V, 5V, GND, ...) on the board-edge row -- Raspberry Pi convention.  Source:
# LilyGo's own pin-map image of the Elite (top view: 3V3 at the USB-C end, inner
# column), cross-checked against GEOMETRY.md's asymmetric hole pattern, which
# puts USB-C at high x.  Rev A/B had pin 1 at the opposite corner, i.e. the
# whole header rotated 180 deg -- HAT GND on the Elite's 5 V.
HDR_X_PIN1 = 56.456
HDR_PITCH = 2.54
HDR_ROW_ODD = 5.900
HDR_ROW_EVEN = 3.360


def pin_xy(pin):
    """G-frame (x, y) of 40-pin header pin `pin` (1..40)."""
    k = (pin - 1) // 2
    return HDR_X_PIN1 - HDR_PITCH * k, (HDR_ROW_ODD if pin % 2 else HDR_ROW_EVEN)


# ELECTRICAL.md: the Elite's WROOM antenna sits under this board here.
KEEPOUT = (58.0, 22.0, 66.22, 44.0)       # x0, y0, x1, y1

EDGE_W = 0.10
SILK_W = 0.15


# ===========================================================================
#  THE CIRCUIT -- one table, used for the symbol library, the schematic and
#  the PCB, so the three cannot disagree.
# ===========================================================================

# LAN8651, 32-VQFN 5x5, exposed pad = VSS.  Pin table verbatim from
# ELECTRICAL.md.  Columns: number, name, electrical type, symbol side.
#   side: L/R/T/B on the schematic symbol body.
LAN8651_PINS = [
    # --- host SPI + reset, left of the symbol -----------------------------
    (11, "CS_N",     "input",          "L", 22.86),
    (12, "SCLK",     "input",          "L", 20.32),
    (13, "SDI",      "input",          "L", 17.78),
    (10, "SDO",      "output",         "L", 15.24),
    (9,  "IRQ_N",    "open_collector", "L", 12.70),
    (8,  "RESET_N",  "input",          "L",  7.62),
    # --- config / analogue, left ------------------------------------------
    (4,  "TEST",     "input",          "L",  2.54),
    (27, "XTI",      "passive",        "L", -2.54),
    (28, "XTO",      "output",         "L", -5.08),
    (26, "RBIAS",    "passive",        "L", -10.16),
    (21, "CCOMP",    "passive",        "L", -12.70),
    # --- bus, right --------------------------------------------------------
    (30, "TRXP",     "bidirectional",  "R", 22.86),
    (31, "TRXN",     "bidirectional",  "R", 20.32),
    # --- configurable IO, right -------------------------------------------
    (18, "DIOA0",    "bidirectional",  "R", 15.24),
    (19, "DIOA1",    "bidirectional",  "R", 12.70),
    (20, "DIOA2",    "bidirectional",  "R", 10.16),
    (22, "DIOA3",    "bidirectional",  "R",  7.62),
    (23, "DIOA4",    "bidirectional",  "R",  5.08),
    (16, "DIOB0",    "bidirectional",  "R",  2.54),
    (14, "DIOB1",    "bidirectional",  "R",  0.00),
    # --- power management / unused, right ---------------------------------
    (32, "WAKE_IN",  "input",          "R", -5.08),
    (24, "WAKE_OUT", "output",         "R", -7.62),
    (1,  "INH",      "open_collector", "R", -10.16),
    (6,  "DNC",      "passive",        "R", -15.24),
    (15, "DNC",      "passive",        "R", -17.78),
    # --- supplies, top -----------------------------------------------------
    (7,  "VDDP",     "power_in",       "T", -7.62),
    (17, "VDDP",     "power_in",       "T", -2.54),
    (29, "VDDA",     "power_in",       "T",  2.54),
    (25, "VDDAU",    "power_in",       "T",  7.62),
    # --- grounds, bottom ---------------------------------------------------
    (2,  "VSS",      "power_in",       "B", -7.62),
    (3,  "VSS",      "power_in",       "B", -2.54),
    (5,  "VSS",      "power_in",       "B",  2.54),
    (33, "VSS_EP",   "power_in",       "B",  7.62),
]
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

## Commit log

2026-09-29 Elite T1S HAT: 10BASE-T1S (LAN8651) board for the LilyGO T-ETH-Elite
    A 4-layer HAT that gives the T-ETH-Elite (ESP32-S3) a single-pair
    automotive Ethernet port, built around the Microchip LAN8651 MAC-PHY.
    - hardware/: KiCad schematic and PCB, all generated by make_t1s_hat.py,
    which also checks the mechanics against GEOMETRY.md, runs DRC and
    writes gerbers and JLCPCB assembly files (base, end-node and
    drop-node variants). DRC 0 errors, ERC 0 errors.
    - firmware/: ESP32-S3 node firmware over OPEN Alliance TC6 SPI, with
    PLCA, a serial console and a W5500 <-> LAN8651 learning-bridge mode.
    - mechanical/: board geometry derived from LilyGo's CAD, and 3D models
    (STL, STEP) with their buil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
    [bom.csv, bom_jlc.csv, stack.stl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]
2026-09-29 Rev B review follow-ups: X7R CCOMP, probe labels, ferrite note, 23 mm
    Checked against the board file and Microchip's documents:
    - C4 (CCOMP) X5R -> X7R (Yageo CC0805KKX7R8BB475, C354262). The
    checklist says 'metal film', the data sheet does not; recorded.
    - J1 pins 15-24 carry all six host signals plus 3V3 and GND: labelled
    on the silkscreen as the bring-up probe points.
    - Ferrite beads need a local 10 uF (checklist); FB1-4 documented as
    0 ohm links, with which the single C6 is compliant.
    - Stack height text corrected to the calculated ~23 mm everywhere.
    - README 'Review notes': why the P N N P connector stays (the node's
    stub is 15.92 mm on both legs; the difference is the through-b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
    [bom.csv, bom_jlc.csv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]
2026-09-29 Correct CCOMP note: the data sheet body also says metal film; freeze Rev B
    DS60001734F's power section asks for "4.7 uF low ESR (metal film)"; only the
    pin table says plain "low ESR". The README review row claimed otherwise.
    C4 stays X7R, now documented as a non-compliant prototype choice with the
    checks the first boards must pass. Adds the Rev B freeze and bring-up order.
    Board geometry and production files unchanged.
    [bom.csv, t1s_hat.kicad_pcb, t1s_hat.kicad_sch]
2026-09-30 Review follow-ups: GEOMETRY split, BOM/doc consistency, CMC void check, DRC clean, UDP sink
    - mechanical/GEOMETRY.md now describes this board only (66.22 x 49.19, no
    notch, 4 holes); the old adapter's outline/notch/6 holes move to
    legacy_adapter_geometry.md
    - L1 documented as the 200 uH ACT1210L-201 actually fitted (prototype
    alternative, EMC validation pending); R1/R2 documented as 0.75 W
    substitute for AN1718's 1 W; C4 marked PROTOTYPE_X7R in ORDERING.md
    - clock section names the load caps C15/C16 (C1/C2 are the bus caps);
    status LEDs marked as firmware mapping pending
    - CMC void forbids tracks on In1/In2/B.Cu; the verifier fails on any
    track or via there, and on F.Cu on anythi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
    [bom.csv, t1s_hat.kicad_pcb, t1s_hat.kicad_sch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]
2026-09-30 JLC CPL in JLC's footprint frame: fix L1 rotation and CN1 origin; D2 restocked
    check_jlc_cpl.py places the EasyEDA footprint of every LCSC part exactly as
    the CPL says and checks each pad lands on ours. Against the plain KiCad
    export it found two parts JLC would have placed wrong:
    - L1: EasyEDA's ACT1210 is drawn 90 deg from ours; CPL 90 -> 0
    - CN1: EasyEDA's origin is the body centre, KiCad's pin 1; CPL now
    gives the pad centroid (5.715 mm)
    Now 0 parts off in all three variants. LEDs are compared by K/A, not
    pad number.
    D2: C89811 fell to 20 in stock; now KENTO KT-0603Y (C2287), cathode on
    the same side. Stock re-checked 2026-09-30. Board unchanged.
    [bom.csv, bom_jlc.csv, t1s_hat.kicad_pcb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]
2026-10-01 t1s_node: optional zenoh-pico over the T1S netif (-DT1S_WITH_ZENOH)
    hello/signal/ping/stats publishers and a cmd subscriber on t1s/t1s-hat-<id>/...;
    RTT measured on the node from pongs echoed by a peer; 'zenoh' console
    command. Stub when built without the flag. README: build line and the
    measured numbers (SPI 25 MHz: 9.0 / 9.5 Mbit/s, ping 0.85 ms).
2026-10-01 Rev C list: node-ID selector, switchable termination, PLCA LEDs; what to keep, from bench measurements
2026-10-01 Rev C: drop the LEDs the LAN8651 cannot drive, route VDDA clear of the choke, status on the Elite LED
    - LAN8651 PADCTRL A0SEL/A1SEL are event capture/generator only - no LED
    function - so D1/D2/R8/R9 go (two extended parts fewer) and DIOA0/1 are
    grounded with DIOA2/3/4
    - VDDA leaves pin 29 by two vias under the top lanes instead of running
    0.25 mm inside L1's outline; the CMC-void check needs no exception now
    - firmware: Elite LED (IO38) shows PLCA state from PLCA_STS (solid / fast
    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
    [bom.csv, bom_jlc.csv, stack.stl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]
2026-10-01 t1s_node: SPI 25 MHz default with step-down, counters, sniff mode, Zenoh remote config
    Written without hardware; builds with and without T1S_WITH_ZENOH, not run yet.
    - bring-up tries the saved clock, then 20/12/4 MHz; status shows the one in use
    - counters: GEM MAC statistics (clear-on-read, summed), TC6 STATUS0/1, BUFSTS, PLCA_STS
    - mode sniff: T1S frames copied out of the W5500, PLCA off, nothing sent on T1S
    - t1s/<node>/config -> whitelisted console command, ack on t1s/<node>/config/ack
2026-10-01 Rev C finished: stock re-read at JLC, L1/MOV lands cross-checked, stale Rev B labels
    - all 16 BOM lines in stock in JLC's assembly warehouse (U1 199); LCSC retail's 0 for
    C25804 is the shop, not the assembly stock
    - L1 land vs JLC's EasyEDA footprint: same pitch, width and inner gap, 0.1 mm toe
    difference; MOV is hand-fit, TDK's own land kept
    - top README / ORDERING / ELECTRICAL / GEOMETRY say Rev C where they meant the current board
2026-10-02 t1s_node: WiFi console (TCP 23) + ArduinoOTA, mode tx (W5500-only endpoint)
    - every print goes through Con: USB serial at once, a queued copy for the TCP client
    - WiFi station from NVS (wifi <ssid> <pass>) or own AP t1s-<id>; started last in setup
    - ArduinoOTA with mDNS hostname t1s-<mac>, password in NVS (ota <pass>)
    - mode tx: no LAN8651, the W5500 as an IP endpoint, for a second board in the PC's place
    - partition scheme app3M_fat9M_16MB: two 3 MB OTA slots (zenoh build is 1.16 MB)
    Builds with and without zenoh; not run on hardware.
2026-10-02 t1s_node: mode tx status prints the W5500's own PHYCFGR (cable link / speed / duplex)
    Read on hardware: 0xfa with no cable = autoneg on, LNK 0, which tells a missing link
    from a driver problem.
    [bridge.h, t1s_node.ino]
2026-10-02 Rev C review fixes: decoupling, RBIAS and crystal at their pins, EP paste clear of vias
    Pre-fabrication review of the Rev C layout. Still Rev C; not ordered.
    - CCOMP: C5 1.4 mm and C4 2.9 mm from pin 21 (were 2.3 / 6.1 mm), trace
    0.30/0.40 mm and 3.0 mm long (was 0.15 mm, 10.1 mm), own ground vias.
    DIOA0..4 tie inward to the exposed pad to free U1's right edge.
    - U1 exposed-pad paste: project-local copy of the TQFN-32 footprint with the
    paste split into 12 windows, each >= 0.15 mm off every thermal via land
    (51 % coverage); land, mask and vias unchanged. Asserted by the verifier.
    - VDDAU: C14/C13 2.1/2.6 mm from pin 25 (were 15.4/15.8 mm).
    - VDDA: C12 5.0 mm of copper from pin 29 (w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
    [bom.csv, bom_jlc.csv, stack.stl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]
2026-10-02 t1s_node: bench fixes from the first run on three boards
    - reg: no crash without a LAN8651 (null gMac; the console's poll killed tx-mode boards)
    - status: rx frame counters at the driver input (rx t1s / rx w5500), no register map needed
    - identify (LED strobe), promisc on|off, phyreset
    - README: the GEM counter addresses read 0 on a real LAN8651 -- marked unverified
    Run on hardware: tx mode, W5500 link/PHYCFGR, SPI step-down without a HAT, WiFi AP.
    [bridge.h, t1s_node.ino]
2026-10-02 t1s_node: drop the guessed GEM counter reads (they stopped the LAN8651 transmitting); paced blast
    Found on the two-ESP bench: with a read of MMS 1 words 0x42..0x69 every 5 s the node sent
    nothing after its first ~5 s; fa23fd0, which never read them, carried 9 Mbit/s. Removed.
    Also: blast takes a target Mbit/s, phy <mode> writes the W5500 PHYCFGR, rxlog, wifi off,
    heap and W5500 socket/SPI state in status.
2026-10-02 t1s_node: us RTT, sink sequence/gap statistics, whole console lines, zenoh backoff
    - rtt <ip> [n] [bytes] [ms]: UDP echo round trip with esp_timer, summary and every sample
    - sink: blast sequence numbers -> loss / reordered / duplicates; inter-arrival histogram
    (20 us bins) -> p50/p90/p99/max (sinkx line); reset is carried out by the sink task
    - Con: one lock across USB serial and the TCP copy -- a zenoh retry printed during a blast
    report cut it in half on hardware
    - zenoh: with no router, retry 3 s doubling to 30 s instead of every 3 s
    [net_console.cpp, t1s_node.ino, zenoh_t1s.cpp]
2026-10-02 t1s_node: Zenoh peer to peer over UDP multicast (no router), on both board kinds
    - default transport: peer, listen udp/224.0.0.224:7447#iface=eth (the iface key is required by
    zenoh-pico's locator check); -DZENOH_ROUTER keeps the zenohd mode
    - every board echoes the others' pings; RTT ring (zenoh rtts), bulk put/count (zenoh blast/sink),
    ping rate, pause/resume of periodic traffic
    - mode tx runs Zenoh too, as t1s-eth-<mac>
    Run on hardware: two boards, sessions up, RTT 5.6-6.0 ms.
2026-10-02 Consistency pass from an audit: docs, schematic notes, one silkscreen line
    Board: copper, pads and zones unchanged (347 items compared); the termination silkscreen line
    reads '49R9 1%' (the fitted part is 0.75 W, the old line said 1 W). Schematic: title rev C,
    clock note CL 12 pF, R1/R2 note >=0.5 W; R3 value 100k 1% (C149504 is 0805W8F1003T5E, F = 1%).
    Docs: 6 extended parts with end/drop (5 unfitted), 15 BOM lines, 34 parts, Rev B never
    ordered, firmware status = runs on hardware, stale LED/riser/580 KB/partition claims fixed,
    min clearance 0.20 and the MOV rule described as written, console list complete (tx, wifi,
    ota, zenoh), relative pins.h link, no local paths. DRC 0/0/0, ERC 0 errors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
    [bom.csv, bom_jlc.csv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]
2026-10-02 zenoh: echo pings from the callback's wake-up, ping/pong as express
    Measured on hardware: no change to the round trip (6.11 -> 6.19 / 6.14 ms median); the cost is
    inside zenoh-pico. Kept as the correct settings; README says so.
    [zenoh_t1s.cpp]
2026-10-02 t1s_node: frame capture (capture start/stop/dump), also in bridge/sniff; Zenoh RTT fixed numbers
    - every received frame (us timestamp, 128 B, interface) into PSRAM; dump as hex for a pcap
    - the Zenoh echo/express change measured again with both boards on the new image: 6.14 -> 5.20 ms
    and 5.58 -> 5.26 ms median; the earlier 'no change' was the HAT still booting an OTA'd image
    - README: flashing after an OTA (erase otadata)
    [bridge.h, t1s_node.ino]
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2026-10-06 t1s_node: report the actual SPI clock; sink rate without the +0.5 % bias; gap histogram to 50 ms
    - bring-up and status print asked and actual SPI clock (80 MHz / integer: 25 -> 26.67)
    - sink: (datagrams after the first) / (first-to-last arrival in us), gap bins 20 us to 2 ms then
    1 ms to 50 ms, percentiles clamped to the max
2026-10-06 READMEs: SPI 25 MHz results were at 26.67 MHz actual; note the old sink bias
2026-10-06 t1s_node: never run SPI above the LAN8651's 25 MHz (25 asked now runs 20 MHz, not 26.67)
2026-10-06 t1s_node: the board's own RJ45 works in node mode (W5500 as a second interface, lan dhcp|<ip>|off); per-driver link events; Zenoh multicast TTL 1 (patch)
2026-10-06 t1s_node: live operator input (w) as 16 B control messages (ctl): timer-paced or on change, echo RTT/loss/deadline, input age
2026-10-06 t1s_node: body events (evt): 12 B turn-signal messages over UDP 5006, acked by the receiver, which shows the indicator on the board LED
2026-10-06 t1s_node: evt codes 4 horn and 5 headlight flash (one-shot LED patterns over the indicator)
2026-10-06 tools/zenoh.lua: Wireshark/tshark Lua dissector for Zenoh 1.x as zenoh-pico sends it (JOIN, KEEP_ALIVE, FRAME/FRAGMENT, PUSH PUT/DEL, DECLARE)
2026-10-06 t1s_node: sync <ip> [n] [ms], two-way time transfer with software stamps (PTP/NTP exchange); bench: offset precision 50-150 us, drift ~1-2 ppm
    [t1s_node.ino]
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2026-10-06 ptp on: enable the PHY packet matcher (match every frame at the SFD) -- the missing piece; LAN8651 hardware stamps work: node-side offset sigma 16.7 us vs 43 us software
    [esp_eth_mac_lan865x.c, t1s_node.ino]
2026-10-06 ptp lock: PI servo on the LAN8651 TSU (step via TA/TSL+TN, frequency via TI+TISUBN), jittered request spacing; locked to ESP-B: mean -3.4 us, sigma 32 us, -22.3 ppm
    [t1s_node.ino]
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
